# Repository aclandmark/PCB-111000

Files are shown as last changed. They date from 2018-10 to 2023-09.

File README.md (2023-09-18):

# PCB-111000

*/*/*/*/*/*/*/*/*/*/*/*/*/*/*/*/*/*/*/*/*/*/*/*/*/*/*/*/*/*/*/*/*/*/*/*/*/*/*/*/*/*/*/*/*/

This project is now obsolete.     The new version is PCB-111000_V2

The winAVR compiler has been replaced by Arduino and Studio 7

MOSFETS used to drive the display have been dispensed with

The pcb is set up usng a UNO and two sketches both of which are based on the sketch "UNO_as_an_AVR_programer"

Sample user programs have been updated in the light of the change from winAVR to Arduino.

The Nano_projects directory contains projects developed for PCB-111000_V2

*/*/*/*/*/*/*/*/*/*/*/*/*/*/*/*/*/*/*/*/*/*/*/*/*/*/*/*/*/*/*/*/*/*/*/*/*/*/*/*/*/*/*/*/*/*/*/*/

56 Projects for the novice C programmer -   Excludes programmer firm ware

Purpose: To introduce newcomers to C-programming for Atmega micro-controllers using the WinAVR compiler.  Programmers, target devices and a display are all provided on the pcb.  Sample user programs are provided to illustrate various applications such as transferring data to and from a PC, reading switches and driving a display.  Finished projects such as a stop watch, reaction time tester or calculator can be operated independently of a PC provided that a 5V USB supply is available.

PCB 111000 Hardware:

    1. An Atmega 328 that drives an 8 digit 7 segment display and downloads user code to an Atmega 168. 
    2. An Atmega 168 for which the user writes simple C-programs.  
    3. Three switches that can be used to provide inputs for the Atmega 168.
    4. An FTDI 230X USB to UART bridge that enables the PCB to be connected to a PC.
    5. A programming interface:  This is normally used to program the Atmega 168 but can also be used 
       to update the Atmega 328 code.
    6. An I2C interface via which user code controls the display.

PCB 111000 Software:

    1. A basic Atmega programmer that resides in the boot partition of the Atmega 328.
    2. An application that drives the display, hosts an I2C interface and includes other functions 
       including a clock/stop watch and arithmetic (known as the mini-OS).
    3. An Atmega 328 programmer that can be downloaded onto the Atmega 168.
    4. Subroutine library to support user code.

Test_file_change

Link to relevent AVRfreaks project

https://github.com/MicrochipTech/avrfreaks-projects/tree/main/projects/pcb-111000-winavr-taster-pcb

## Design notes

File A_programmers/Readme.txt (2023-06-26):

ATMEGA_project_work_BKP_30_Sept_2022\
I2C_apps_project_V10\
Programmers

For compatible programmers

Used in mini-OS_Version_20
2_pcb_Bootloader_V4_21_CA
3_pcb_Bootloader_V4_22_CC

Use  External programmer V2_30B	which ensures Auto cal runs on Atmega 328

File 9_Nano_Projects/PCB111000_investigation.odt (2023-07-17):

Development of Github_PCB-111000

Create new folders 9_Nano_Projects

and Resources_nano_projects

Go to ATMEGA_project_work_BKP_30_Sept_2022\I2C_apps_project_V10 and

Copy the files in 2_User_projects_V1_9\Resources_V12 to Resources_nano_projects

Create a new Arduino project 1_first_project

and save it under 9_Nano_Projects

Note that folder 1_first_project is created for the project

Open 2_User_projects_V1_9\….\….\Open Proj_1A1

Copy its contents into the Arduino project

Copy Proj_1A1 hex file and

Proj_1A1_header_file

into the 1_first_project folder along side the 1_first_project project

Rename the header file First_project_header

Initial tests

Upload the hex file to a PCB111000

Check it runs immediately following an -r- keypress

Gives Version data following an -x- keypress

Close and reopen the Arduino Project so that it includes the header file

Edit the #include statement to read #include "First_project_header.h"

Compile the project using Nano board Atmega 168 processor

Using setup_HW_basic;

and setup_HW

Check the following text is printed out OK

1 for OS version

2 for system data

3 Message from the OS (x to escape)

The Default project runs correctly

OS version

OS: I2C_V20_0_CA

System data:

SW information: Operating system I2C_V20_0_CA Projects V1_9 and Bootloader V4_21_CA. External programmer V2_30B

Actual operating system is Github_PCB-111000_V2\Mini-OS_V22

Update mini-OS

Github_PCB-111000 contains mini-OS version12 and 13.

Replace this OS with mini-OS_Version 20 copied from

ATMEGA_project_work_BKP_30_Sept_2022\I2C_apps_project_V10

Rebuilding mini-OS_V20 will require use of Atmel Studio 7.

Reprogramming the Atmega 328 with require the programs saved under

ATMEGA_project_work_BKP_30_Sept_2022\I2C_apps_project_V10

To update the mini-OS DO NOT EXPECT TO NEED TO DO THIS

At the p/r prompt put “4_Project_pcb_168_V2.30B” on the Atmega 168

At the ‘P’ prompt press

‘P’ to reprogram the mini-OS

‘E’ to update the “Hello world” file.

Note: Other programmers that should no longer be needed.

Version A: Same as Version B but B has one extra line to trigger auto cal of the 328.

4a_Project_pcb_328_V2.31A runs on an Atmega328

Programmer_pcb_328_V1.10 runs on a 328 and is used to put V2.30B on a 168 or replicate itself on another 328

6_BL_programmer_V1_5 was a development tool and is no longer required

If more boards are to be built a UNO will be used to put V2.30B onto an Atmega 168 and also calibrate it.

The Atmega 328 programmer applies the following config bytes to the 168

FF D5 C2 EB

V1.10 applies FF D7 E2 EB

Differences effect the brown out level and start up time.

New locations for user cal bytes Check carefully that these are always used

0x1FF User calibration byte

0x1FE User calibration byte

0x1FD Default calibration byte

0x1FC PRN generator random number HB

0x1FB PRN generator random number LB

Note: Only two locations are used here but write to EEPROM every 45 secs

2_User_projects_V1_9\Proj_9_System_projects\Proj_9A_168_manual_cal()

writes EEPROM location 0x1FA to zero.

No reason for this has been found and the line should be commented out

Problems

1 Note old problem with redefinition of

volatile char PCMSK0_mem, PCMSK2_mem;

in File I2C_subroutines_2

void I2C_Tx_float_display_control(void)

and #include "../Header_files/I_O_from switches.h"

Solution copied from PCB111000_UNO Compiles OK but not fully tested.

2 I2C_subroutines_2 line 121 SOLVED

Commented out for time being.

Calibration programs All OK

Copy the following two calibration routines to

9_Nano_Projects\System_programs

2_User_projects_V1_9\Proj_9A_168_manual_cal

and \Proj_9B_168_auto_cal

Compile with Arduino_nano_168 and calibrate two pcbs successfully.

Note Problem 2 above

Note: The Atmega 328 (mini-OS device calibrates itself automatically at every POR)

provided the DPDT is switched to the right.

1_first_project 12 examples

Example 1 Ramp with SW reset Tested OK

Example 1A Ramp with WDT generated reset Tested OK

Example 2 Back and forth with WDT Tested OK

Example 3 Chase (spurious wdr(); removed) Tested OK

Example 4 Single ellipse (spurious wdr(); removed) Tested OK

Example 5 Double ellipse (spurious wdr(); removed) Tested OK

Example 6 Upper/lower see saws Tested OK

Example 7 Moving top Tested OK

Example 7A Moving top (with reset on sw3) Tested OK

Example 8 Leds leapfrog WDT added Tested OK

Example 9 LEDS light up in random order (with reset) Tested OK

Example 10 Default program with WDT Tested OK

Tested with setup_HW_extra

Example_1 Modes 0 – 4 tested OK Saved as Example_1E

Example_4 Modes 0 – 4 tested OK Saved as Example_4E

Example_7 Modes 0 – 4 tested OK Saved as Example_7E

Example_9 Modes 0 – 4 tested OK Saved as Example_9E

2_Receiver_Transmitter_Basic

Example_1 Tested OK

Example_2 Tested OK

Example_3 Tested OK

Example_4 Reset implemented Tested OK

Example_5 Reset implemented Tested OK

Example_6 Reset implemented Tested OK

Example_7 Tested OK

Example_8 Tested OK

Example_9 Tested OK

Tested with setup_HW_extra

Example_1

Example_3

Example_5

Example_7

3_Interrupts_and_switches

Basic HW HW_Extra

3A_UART_timer_interrupts OK OK

3B_Pin_Change_Interrupt OK OK

3C_reaction_time_tester OK OK

3D_timer_PCI_interrupts OK OK

3E_Keypress_logger OK OK

3F_Prime_numbers OK OK

3G_Prime_numbers_plus OK OK

4_binary_and_bit_operations

1_Bit_ops_1 OK OK

2_Bit_ops_2 OK OK

3_Division_subroutine OK OK

4_Char_to_binary OK OK

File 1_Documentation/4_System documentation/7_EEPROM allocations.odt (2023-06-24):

Atmega 328: the first 0x200 bytes. These are reserved for user data

Bytes 0-1 First address available for numeric data

Byte 2 Number of bytes used for numeric data

Bytes 3-4 First address reserved for the application

Bytes 5-0x1FF Available for strings and numeric data

As supplied on the project pcb, bytes 5 to 0x1FB are occupied by strings.

No space is reserved for use by the mini-OS and no numeric data is stored.

Locations 0x01FC, D, E and F are unused.

Atmega 328: The second 200 bytes These are reserved for use by the mini-OS

Bytes 0x200 – 0x3F6 contain a copy of the strings required to use the Atmega 168 as a programmer.

0x3F7 to 0x3FA: These 4 bytes are not used.

0x3FB controls display intensity

0x3FC contains 1 for diagnostic mode (user pressed 'x' at the “p/r...” prompt) otherwise contains 0.

0x3FD contains the default value of OSCCAL (supplied by Atmel)

0x3FE and 0x3FF contain the user calibration values of OSCCAL.

Atmega 168 bytes 0-0x1FF

Bytes 0 – 0x1F6 : These contain strings used when the Atmega 168 is programmed with “1_ATMEGA_Programmer_V2.29A” for updating the mini-OS or programming the Atmega 328 EEPROM.

Note: this space can be overwritten by project SW and the strings restored when needed.

0x1F7 and 0x1F8 User cal byte

0x1F9 Default calibration byte

0x1FA – 0x1FD 4 unused bytes

0x1FE and 0x1FF Seed for 16 bit PRN generator

Modified as below

0x1FF PRN generator random number HB

0x1FE PRN generator random number LB

0x1FD PRN generator random number HB

0x1FC PRN generator random number LB

0x1FB PRN generator random number HB

0x1FA PRN generator random number LB

0x1F6 PRN EEPROM location offset 0, 1 or 2

Programming the Atmega 168 EEPROM

This is normally done on the programmer pcb using “1_ATMEGA_Programmer_V1.08” running on the Atmega 328.

Echo the “User Prompt” and then press 'P', 'E' and 'W'.

Note:

The Atmega 168 flash should also be programmed with 1_ATMEGA_Programmer_V2.29A.hex”

Programming the Atmega 328 EEPROM

This is normally done on the project PCB using “1_ATMEGA_Programmer_V2.29A.hex” running on the Atmega 168.

When programming the EEPROM press

"E" to program addresses 5 to 0x1FF or

"e" to program addresses 0x200 to 0x3FD or

"D" to delete the entire EEPROM up to 0x3FD (preserves cal bytes)

When verifying the target EEPROM press "r" or "R".

Note: An Atmega 328 programmed with “1_ATMEGA_Programmer_V1.08” can be soldered onto a project pcb if an unprogrammed Atmega 168 has already been soldered in.

C-programming for beginners: EEPROM allocations

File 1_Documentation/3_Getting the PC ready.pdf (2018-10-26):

PCB 111000: Getting the project PC ready

Disclaimers

PCB 111000 has been developed for educational purposes only. All associated software is supplied “as is” with no implied warranty or assumption of fitness for any purpose.

Instructions presented below involve making changes to a PC. They should only be carried out by a competent person who judges that to do so will in no way impair the computer performance or put at risk in any way the data already stored on it. Permission of the owner of the PC should also be sought.

Please also see disclaimers published with WinAVR.

Summary of the steps involved

Getting the PC ready involves carrying out the following steps.

Downloading and installing the WinAVR compiler and Programmers Notepad (pn) Fixing an error in the WinAVR installation
Doing a test compilation
Downloading drivers for the FX230 USB chip
Downloading a terminal program
Running the test project
Downloading a bit of help from the web
Accessing the WinAVR programs

Downloading WinAVR and programmers notepad (pn)
Go to
https://sourceforge.net/projects/winavr/files/WinAVR/20100110/
Download and run WinAVR-20100110-install.exe.
Select all the defaults i.e.
Install in the root directory, Install files, Add directories to path, Install programmers notepad. After completing the installation navigate to C:\WinAVR-20100110\pn.
Right click on the “pn” application and select “Create shortcut”.
Drag and drop the short cut onto the desktop.

Fixing the Installation error Before proceeding there may be an installation error to deal with. Check the reviews tab on the download page to determine whether or not it has been fixed. The problem may be because WinAVR is installed in the root directory rather than under “Program Files(x86)”. There are various ways of getting around it. The option selected here is to go to the following web page which discusses the problem in some detail http://www.avrfreaks.net/forum/windows-81-compilation-error

Then click on the link: http://www.madwizard.org/download/electronics/msys-1.0-vista64.zip This downloads the file “msys-1.0-vista64.zip”. Extract file “msys-1.0.dll”.
Use it to replace the file of the same name in the following directory: WinAVR-20100110\utils\bin.

Doing a test compilation (shows screen shot of programmers notepad (pn)

Open pn from the desktop.

The first time this is done the dialogue boxes “Text Clips”, “tags”, “projects” and “scripts” are all present. They are not used by the PCB 111000 projects can all be closed.

Open the first User project “Proj_1A.c”.
Then click on Tools:
[WinAVR]Make All.
An Output dialogue box tracks progress. The important thing apart from the absence of errors is the amount of program and data space used: 17.5% and 6.5% in this case.

Click on Tools:
[WinAVR]Make Clean
to delete files generated by the compiler that are not used by PCB 111000 projects. (Note the “makefile” has been changed slightly to ensure
that the .hex file is not also deleted.)

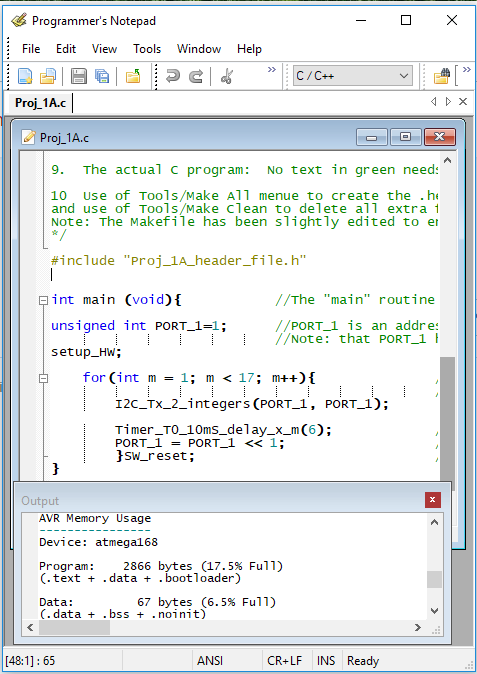
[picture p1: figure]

Downloading drivers for the FX230 USB chip
Having connected PCB 111000 to the PC for the first time this usually happens completely automatically in several minutes. Opening “device manager” enables this process to be tracked and also reveals the “comm port number” assigned to the pcb which should be remembered.

Downloading a terminal program
The terminal program enables PCB 111000 to communicate with a PC.

Two programs have been used during development of the PCB 111000 projects. The first is Br@y++ for which there are several versions. The simplest and most suitable can be obtained by going to
https://www.avrfreaks.net/forum/where-download-brays-terminal and then clicking on http://www.smileymicros.com/download/term20040714.zip?&MMN_position=42:42

Alternatively go to https://sites.google.com/site/terminalbpp/ Version Terminal20130116 is know to be suitable (but click the auto scroll box). This version must be used if the "comm port number exceeds 7.
Once the program has been downloaded it can be copied to the desktop or a short cut can be used if wished.

TeraTerm: This is a good alternative. A google search will quickly locate it.
(For example try https://tera-term.en.lo4d.com/). When installing Tera Term accept all the default settings.

Setting up the Br@y++ terminal program (includes a screen shot of Br@y++)

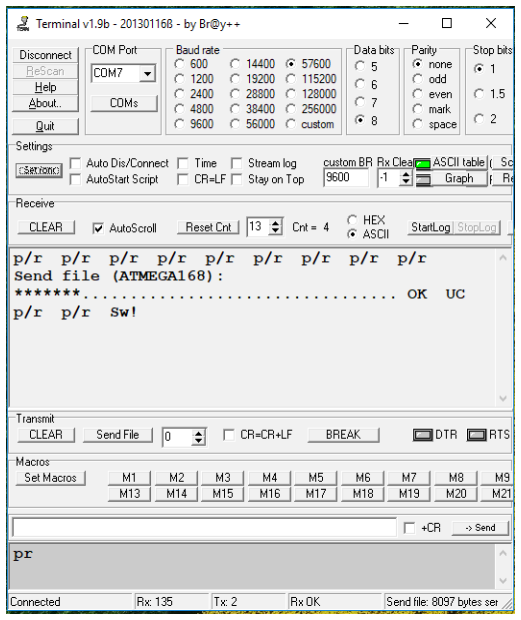
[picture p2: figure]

Connect PCB 111000 to the PC before
opening the terminal program.

The program automatically scans the USB ports and assuming that PCB 111000 is detected it is then necessary to select the correct “comm port number” and click on the “connect” button.

Then set the program as follows: Baud rate: 57600, 8 data bits, 1 stop bit, no parity and no flow control. Click the auto scroll box (if present) and adjust the font.

Note the two text boxes, one for receive and one for transmit. Ensure that the cursor has been placed in the lower box before typing the characters “p” and “r” which will then be transmitted.

Running a test program
Switch the DPDT switch to the RHS.
Press the vertical push button switch.
The Terminal program should display the user prompt p/r p/r …… Press -p- on the keyboard.
The message “Send file (ATMEGA168):” will be displayed
Send the file Proj_1A .hex.
At the p/r prompt press -r- and operate the DPDT switch when instructed. The PCB 111000 leds should now flash.
If they do so then setup and installation have been completed successfully

Setting up the Terra Term program (includes a screen shot of Tera Term)

Connect PCB 111000 to the PC before
opening the terminal program.

As soon as the dialogue box appears click on the serial button and then click on OK (assuming that the PCB 111000 has been detected).

Using the “setup menu” select serial port”, Set the baud rate to 57600 and operate the pcb switches so that the p/r.... prompt appears.
Then select a suitable font.
Finally use “Setup/Save setup” selecting the name “TERATERM”.

The next time Tera Term is used it will start up as wanted immediately.

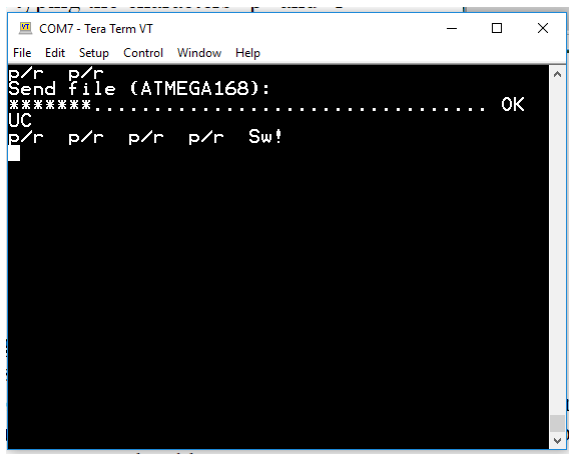
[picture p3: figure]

Note: There are no separate Receive and Transmit boxes and key presses are not echoed

Downloading a bit of help from the web
The following resource gives an excellent introduction to C and the Atmega devices and also gives help in driving the Br@y++ terminal and programmers notepad.
Do a google search on “C Programming for Microcontrollers”. This leads to the book by Joe Pardue of SmileyMicros.com
(Or try “https://epdf.tips/c-programming-for-microcontrollers.html”.)

Accessing the WinAVR programs

Left click in the “Windows” icon or press the “Windows” key.
Then scroll down the list of programs until the WinAVR-20100110 directory is reached.
Open it to reveal various applications and manuals any of which can be pinned to the start bar if required.

Mfile[WinAVR] is used to create “makefiles” which together with “pn” control the operation of the WinAVR compiler on behalf of the user.

Note: There is no need at this stage to access any of these programs. “Programmers notepads”(pn) acts as a development environment and automatically calls WinAVR when required. Additionally copies of “makefile” are already included with each project.

Operation (overview only)

1. Operation is controlled via two switches.
2. A double pole double throw (DPDT) which switches the USB bridge between the Atmega 328 and 168 and controls the external reset pin of the Atmega 168 (see photograph).
3. A push button (PB) which provides an external reset to the Atmega 328, which in turn initiates the bootloader causing it to generate the following user prompt “p/r p/r p/r.........”.

### 4. Operation of the pcb when power is applied:

5. The Atmega 328 automatically runs the mini-OS and provided that the Atmega 168 is connected to the USB bridge the user code will run (even from a 5V supply).

### 6. Programming the Atmega 168 and then allowing it to run:

7. Connect the pcb to a PC run the terminal program and select a Baud rate of 57600.
8. Use the DPDT to connect the Atmega 328 to the PC.
9. Operate the PB, press “p” at the user prompt and send the hex file when requested.
10. Press “r” when the user prompt is repeated, then operate the DPDT when requested.

Photographs of the PCB

View of the Atmega 168
Pin 1 closest to the DPDT

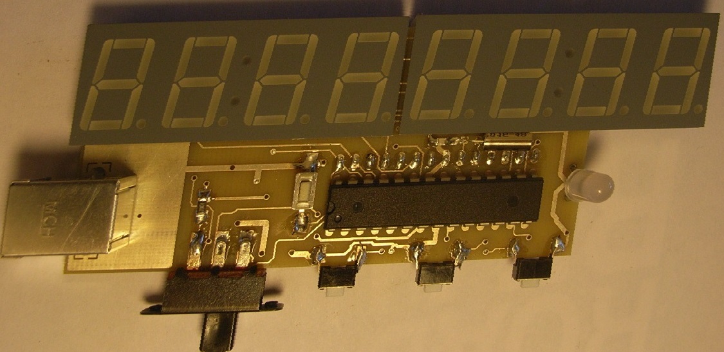
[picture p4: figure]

Note the DPDT switch

To connect the USB bridge to the Atmega 328 push the slider to the right.
To connect the Atmega 168 push it to the left.

Note the vertical push button switch.

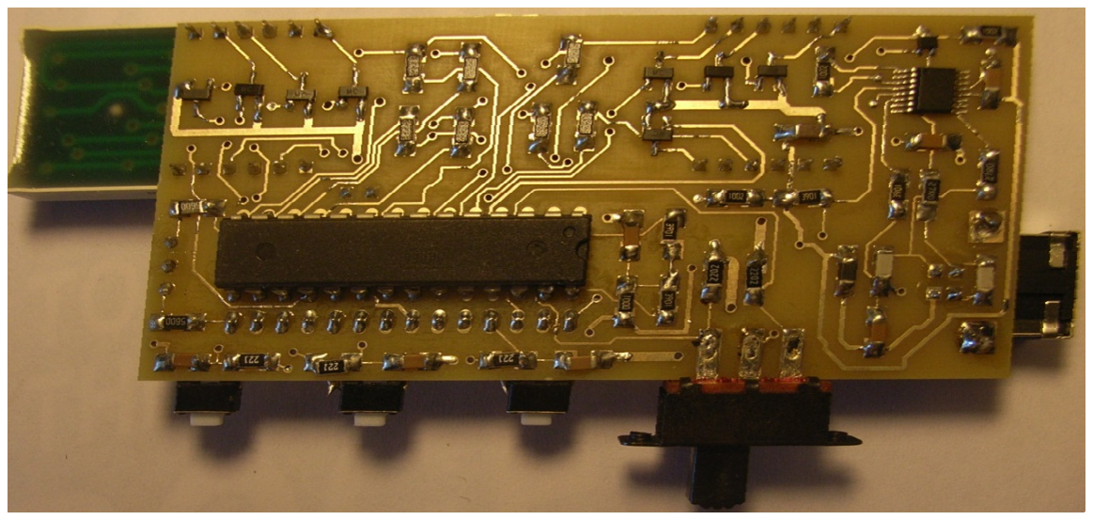
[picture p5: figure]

View of the Atmega 328
Pin 1 closest to the DPDT

Note the three horizontal switches that can be used to provide inputs for the Atmega

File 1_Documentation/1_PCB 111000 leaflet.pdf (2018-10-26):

Presenting PCB 111000: 56 Projects for the novice C-programmer

Features Atmega devices, programmer and mini-OS and Introduces the free WinAVR compiler

Target audience: Anyone wishing to try out WinAVR, who also wants a basic pcb to check that they have set up their WinAVR development environment correctly without having to worry about: hardware, programmers, configuration bytes, makefiles, projects, power supplies or any knowledge of electronics and

1. Who would like a brief introduction to writing C for the Atmega family of devices and using it to set up some of the on-chip peripherals.
2. Who would like sample projects, each of which comes with a commentary and provide an introduction to:
a. Basic C features including: loops, strings, variables, types, logic, binary, hex.
b. Basic hard ware features including: Timer/counters, the watchdog timer, the UART, interrupts, the EEPROM, Reset functions, displaying numbers, data input using the user switches, the I2C bus.
c. The WinAVR maths library functions and some of the I/O subroutines.
3. Who would like a platform on which to try out some on the numerous program segments available on internet forums.

System description

The pcb contains the following circuit blocks:

1. An Atmega 328 that drives an 8 digit 7 segment display and downloads user code to an Atmega 168. (See Figure overleaf.)
2. An ATMEGA 168 for which the user writes simple C-programs
3. Three switches that can be used to provide inputs for the ATMEGA 168
4. An FTDI 230X USB bridge that enables the module to be connected to a PC.
5. A programming interface: This is normally used to program the ATMEGA 168 but can also be used to update the ATMEGA 328 code.
6. An I2C interface via which user code controls the display.

System Diagram

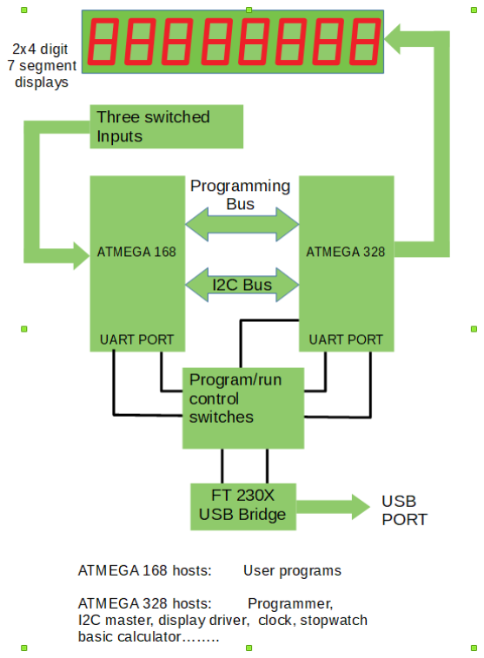
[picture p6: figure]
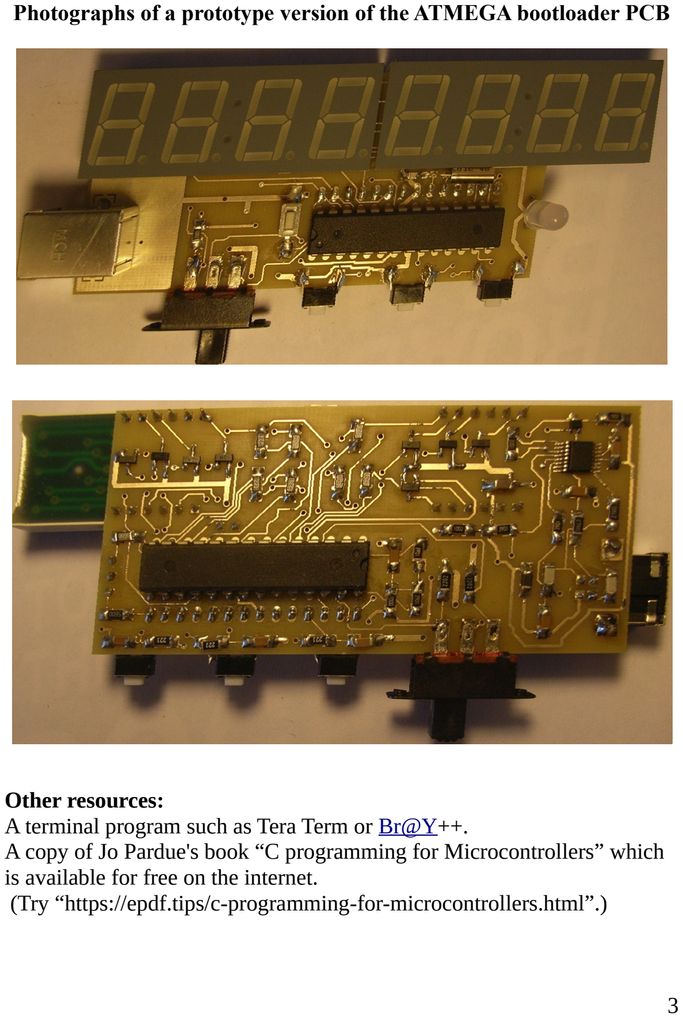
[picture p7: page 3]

Photographs of a prototype version of the ATMEGA bootloader PCB

Other resources:
A terminal program such as Tera Term or Br@Y++.
A copy of Jo Pardue's book “C programming for Microcontrollers” which is available for free on the internet.
(Try “https://epdf.tips/c-programming-for-microcontrollers.html”.)

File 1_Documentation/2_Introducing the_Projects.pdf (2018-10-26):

PCB 111000: Introducing the Projects

It is hoped that newcomers to the C programming language and microcontrollers will find that these projects offer them a basic introduction to:

the WinAVR development system, Programmers notepad and the makefile
the C-programming language and the ATMEGA hard ware (HW)
numbers in binary and visual form and logical and numeric operations

It is also hoped that the projects will offer
A bit of fun to share with friends
The odd useful application such as a clock/ stop watch or simple calculator Templates upon which newcomers can develop their own projects

Note: It is not intended that these projects be substituted for a C course or demonstrate the accepted or optimum way of doing things.

The Projects Projects are grouped into nine separate directories. Proj_1_Led_display_32_element
Proj_2_Led_display_56_element
Proj_3_numbers_and_strings
Proj_4_Data_entry_PCI
Proj_5_Clocks_and_stop_watches Proj_6_Logic_the_EEPROM_and_more Proj_7_Real_numbers
Proj_8_Using_the_C_maths_library
Proj_9_System_projects

The idea is that that each project should explore one new topic, however this was often found to be too restrictive. It is therefore suggested that some projects are worth revisiting later on rather than struggling with when when things are not immediately clear.

Proj_1 and 2

These cover most of the basic C and HW features to be introduced including: The main routine and subroutines
Program flow control and structures
Defining data items and data arrays
Communicating with a PC
Strings and pointers
Displaying numbers
Timers (T0 to T2) and the watchdog timer (WDT)
The EEPROM (memory that survives power disconnection)
UART (Receiver/transmitter) for communication with a PC
The input/output pins (I/O pins)
System Reset: | Power on reset (POR), WDT reset and External reset
Interrupts: | Timer, WDT, UART, PCI (pin change interrupt)
I2C bus: | Which is used to share data between the two devices

PCB 111000: Introducing the Projects

Proj_3_numbers_and_strings These cover the askii code and numbers in string and binary format including:
Sending symbols, text and numeric strings to the PC
Entering integers at the keyboard and converting them to binary numbers
Sending binary numbers to the eight digit display and the PC
Scientific notation
Hex numbers
Division with rounding
Trapping overflow in multiplication

Proj_4_Data_entry_PCI These cover the operation of “pin change interrupt” including Configuring the Atmega device for PCI
Reading the three project switches responsible for generating a PCI
Delaying and restoring PCI (putting it on hold and responding later on)
Disabling PCI, Clearing PCI and switch bounce
Entering numeric data using switch presses.

Proj_5 Clocks_and_stop_watches Mainly just for fun including:
An attempt to produce something useful
A combined clock stop watch that makes more ambitious use of the I2C bus and an excuse to study mini-OS (Operating System) code in some detail.

Proj_6_Logic_the_EEPROM_and_more Odds and ends including: Saving strings to the EEPROM for use by a client program.
Logical and bit operations
Prime number generation
Fruit machine simulation

Proj_7_Real_numbers Explores the acquisition and processing of real numbers: Conversion of decimals numbers between 0 and 1 to binary and back again
Converting a real number into a fixed point binary number
Using twos complement to obtain a negative number
Conversion of a real number to a floating point number with 32 bits for the decimal part and eight bits for the exponent
Basic arithmetic with fixed point and floating point numbers

Proj_8_Using_the_C_maths_library Explores the use of the C library functions to
Input strings and numbers from the keyboard and print results to the screen Input and process data from a .csv file
Use of “sprintf” to display results on the 8 digit display.
Acquire floating point numbers from the project switches
Proj_9_System_projects | These include:
Re-calibration of both devices
Re-initialising the Atmega 168 EEPROM following its use for project work Confirming correct operation of the display one digit at a time.

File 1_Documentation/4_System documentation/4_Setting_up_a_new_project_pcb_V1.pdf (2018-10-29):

PCB 111000: Setting up a new project pcb

Step 1 Initial assembly

Assemble the pcb with all surface mount components, starting with the mini-MOSFET and then the FT230X USB transceiver. Finally add the USB socket and connect the pcb to a PC. The FTDI device will request drivers (via the internet or a disc). The pcb will then be assigned a “com port” number (watch “device manager” window for details). When this is complete load the switches and LED.

Step 2 Adding the Atmega 168 and 328.

Use the programmer pcb to program:

the flash (program memory) of an Atmega 168 with “1_ATMEGA_Programmer_V2.29A.hex”
and its EEPROM with “ATmega programmer_EEPROM strings.txt”.

(see “Sys_documentation\5_The_programmer_PCB_V1” and also calibrate the device if necessary.)

Fit it to the upper side of the project pcb, closest to the pcb edge and with Pin 1 closest to the DPDT. Connect the pcb to a PC and run a terminal program.
Switch the DPDT left and the Atmega 168 should generate the “User prompt P P P | ”
Press 'X' and the pcb should respond with the following message “Target not detected”.
An unprogrammed Atmega 328 should now be fitted to the lower side of the pcb (Pin 1 closest to the DPDT) and the watch crystal should also be added.

Note: When using the Atmega 168 running “1_ATMEGA_Programmer_V2.29A” to program the Atmega 328 responding to the user prompt with:

‘X’ sets the reset vector to location 0x0000
‘P’ sets it to the start of the boot partition
‘P’ is only required when the mini-OS is being programmed
Step 3 Loading the Atmega 328 with the mini-OS

Switch the DTDP to the left.
At the “User Prompt” press 'P' three times.
When requested send file

“1_I2C_V12_0_CC_part_1.hex”, then when the download stops send “2_I2C_V12_0_CC_part_2.hex” and finally send “3_AT_bootloader_V4_22_CC.hex”

Press 0 at the “intger(0-FF)?” prompt.

The programmer responds by verifying the number of instructions that have been programmed. Additional data given includes:
The programmed configuration bytes of the Atmega 328 for which critical parameters are:

PCB 111000: Setting up a new project pcb

Reset vector: Start of the bootloader code.
External reset, serial programming, watchdog under program control EEPROM preserved through “chip erase”
Use of internal 8MHz clock.
3.9V brown-out

The calibration bytes refer to the Atmega 168 programmer. If it has been calibrated by project SW then the calibration data is duplicated.

Step 4 Program the Atmega 328 EEPROM

At the “User Prompt.” press 'P', 'P', 'e', 'W'
At the “intger(0-FF)?” prompt press '0'.
Send text file “ATmega programmer_EEPROM strings.txt”.
Notice that the strings are loaded into locations 0x200 to 0x3F6.
Note: This area of the EEPROM is used to back-up the programmer strings required if the Atmega 168 is to host “AT_Programmer_V2.29A”.

Repeat the process but press 'P', 'P', 'E', 'W'
Send file “Hello_world.txt”
Note that the strings are stored between location 0x5 and 0x1FC (503 characters)
This file can be replaced by any similar file of size 507 characters or less which can also contain numbers (additional characters will be ignored).
The contents of the EEPROM can be verified by pressing PPER or PPer at the user prompt.
Step 5 Calibrating the Atmega 328

The mini-OS includes an auto-cal routine that runs when power is applied. However users can also run “Proj_9C_ATMEGA328_manual_cal” if desired.
To do this:
Switch the DPDT to the right and press the vertical push button switch.
Note the “p/r p/r p/r ….” user prompt. Press 'p'
Send file “Proj_9C.hex” when requested
Press 'r' and operate the DPDT switch
The manual calibration routine will now run.
Step 6 Testing the project_pcb

At this stage the display modules can safely be fitted. It is often found that one or more of the display segments fails to work due to a dry joint or solder bridge. Fault finding is complicated because the display is driven by a multiplexer.

Project “Proj_9E_Test_PCB_Assembly” is therefore supplied to test the operation of the assembly. The multiplexer is disabled and digits and segments can be individually tested and faults located if any fail to work.

PCB 111000: Setting up a new project pcb

Driving the digits and segments

View of pcb from track side showing the pins of one of the four digit displays.

Letters refer to the individual segments.
Numbers refer to the individual digits.

Pin 3 is not used. It is provided to drive a decimal point or colon depending on which display module is used.
Pin-out of the display modules

Looking at the pcb from above the digits are numbered from left to right as follows:

Dig 7 Dig 6 Dig 5 Dig 4 Dig 3 Dig 2 Dig 1 Dig 0

Looking at the circuit diagram two displays are shown. Dig 4 to 7 are in the upper display and dig 0 to 3 in the lower display.

All digits are driven by the Atmega 328 which is on the lower surface of the pcb.

The Atmega 328 pins that drive the digits are as follows:

Pin 19 drives dig 7 | Upper display pin 12
Pin 23 drives dig 6 | Upper display pin 9
Pin 24 drives dig 5 | Upper display pin 8
Pin 25 drives dig 4 | Upper display pin 6
Pin 14 drives dig 3 | Lower display pin 12
Pin 16 drives dig 2 | Lower display pin 9
Pin 17 drives dig 1 | Lower display pin 8
Pin 18 drives dig 0 | Lower display pin 6

The segments are driven by the Atmega 328 as follows: a pin 15
b | 4
c | 5
d | 6
e | 11
f | 11
g | 13

pin 1

7 | 12

6

B 3 2 F A 1
4 G C D E

Edge of PCB

PCB 111000: Setting up a new project pcb

Alternative method of setting up the project PCB firm ware

If the Atmega 168 is soldered onto the project pcb before its flash has been programmed:

Plug an Atmega 328 into the programming PCB and program
its program memory with “1_ATMEGA_Programmer_V1.08_Q.hex”.

(see “Sys_documentation\5_The_programmer_PCB_V1”)

Then press 'P', 'P', 'E', 'W' to program its EEPROM with “ATmega programmer_EEPROM strings.txt”. Note: Text will be loaded into addresses 0x200 to 0x3F6.

Solder this IC onto the project PCB and use it to program the Atmega168 with “1_ATMEGA_Programmer_V2.29A.hex” and then continue as above.

Note: Programming can also continue correctly even if the EEPROM of both devices are unprogrammed. However there will be almost no device generated prompts.

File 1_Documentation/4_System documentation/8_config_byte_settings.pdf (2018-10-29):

PCB 111000: Fuse settings for the Atmega devices

Fuse settings enable users to configure certain elements of the Atmega hardware (HW) at programming time. Once these choices have been made they stand until the device is reprogrammed. The following configuration choices have been made for the project and programmer devices:

The System Clock:

The internal 8MHz RC oscillator is selected
No clock prescaling is implemented
No clock output is implemented.
The start up timer (SUT) is either set to 65mS or is disabled.

Note
The SUT holds the device in reset to give the dc supply and clock frequency time to stabilize.
The SUT can be disabled if the brown out detector (BOD) selected. The BOD holds the device in reset until the dc supply reaches a preset level.

BOD detector
This is implemented for the project pcb so that it can safely be used with batteries.
The brown out voltage level is set to 2.7V ± 0.2V.

Note:
The BOD uses an internal 1.1V reference which it shares with the Analogue to digital converter (ADC). The ADC which is disabled is set to use AVCC as its voltage reference.
The BOD protects memory that can become corrupted if the dc supply momentarily dips by putting the chip into reset.

The boot partition (implemented on the project pcb Atmega 328).
This is implemented by:
Setting the size of the boot partition to 2048 words (4096 (0x1000) bytes)
Setting the reset vector to location 0x7000 (the start of the boot partition).

Note: Where no bootloader code is required the reset vector is set to location 0x0.
In this case the size specified for the boot partition is not important and the application code can use the entire 0x8000 byte memory space.

Other settings
External reset | Enabled
Debug wire | Not used
Serial programming | Enabled
Watch dog timer (WDT) | Under programmer control
EEPROM memory | Survives chip erase
Memory lock bytes | No memory lock features are enabled.
| This byte is always set to 0xEB

Note: Users should never need to change the Configuration bytes

PCB 111000: Fuse settings for the Atmega devices

Project PCB fuse settings for the Atmega 328
Extended fuse byte 0xFD
bit 7-3 These bits are not used, and are each set to 1 (their default value) bit 2-0 These bits (101) set the brown out voltage to 2.7V.
Fuse byte high 0xD0
bit 7 1 | External reset enabled
bit 6 1 | Debug facility disabled
bit 5 0 | Serial programming enabled
bit 4 1 | Watch dog timer under programmer control
bit 3 0 | EEPROM memory preserved during chip erase.
Bit 2 0 | Bits 1 and 2 set the size of the boot partition
bit 1 0 | A setting of 00 gives 2048 words the maximum possible size
bit 0 0 | Sets the reset vector to location 0x7000 (the start of the boot partition)
Fuse byte | 0xC2
bit 7 1 | Divide clock by 8 disabled
bit 6 1 | No external clock output
bit 5 0 | Bits 5 & 4 define the Start up time (SUT)
bit 4,3 0 | SUT is disabled since brown-out detector is set
bit 2 0 | Bits 3-0 select clock
bit 1 1 | These settings select
bit 0 0 | the 8MHz internal oscillator
Note: When only running a single application or when loaded onto a programming pcb the following changes are made to the Atmega 328 fuse bytes:
The extended fuse byte becomes 0xFF | The DOB is disabled
The fuse byte high becomes 0xD7 | The reset vector is location 0x0. Bits 1&2 are non-critical
The fuse byte becomes 0xE2 | SUT is set to 65mS
Fuse settings for the Atmega 168 when running projects
Extended fuse byte 0xFF
bit 7-3 These bits are not used, and are each set to 1 (their default value)
bit 2-1 These bits are used to set the size of the boot partition. Here their settings are not critical. Bit 0 This bit sets the reset vector to location 0x0.
Fuse byte high 0xD5 | Use D7 when running Programmer V2.29A (no BOD)
bit 7 1 | External reset enabled
bit 6 1 | Debug facility disabled
bit 5 0 | Serial programming enabled
bit 4 1 | Watch dog timer under programmer control
bit 3 0 | EEPROM memory preserved during chip erase.
Bit 2 1
Bit 1 0 Bits 0 – 2 set the brown-out level to 2.7V.
Bit 0 1
Fuse byte C2 (The settings are identical to those of the Atmega 328) Use E2 when running Programmer V2.29A (65mS SUT)

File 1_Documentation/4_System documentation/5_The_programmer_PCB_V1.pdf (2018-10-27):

PCB 111000: The_programmer_PCB

The programmer_PCB is almost identical to the project_PCB however the Atmega 328 is loaded with “4_ATMEGA_Programmer_V1.08_T.hex”. The Atmega 168 is replaced with a dil socket (dual in line). Watch crystals are connected between pins 9 and 10 of both ICs rather than just the Atmega 328. The vertical push button switch is not loaded nor are the three switched used to provide user input.

This pcb can used to:
1 | Calibrate an Atmega 168 using:
| “11_Auto_cal_168_V1_5.hex” and
| “13_Manual_cal_168_V2_5.hex”.
2 | Prepare the Atmega 168 for use in a project pcb by:
| Programming its flash with “6_ATMEGA_Programmer_V2.29A.hex”
| and its EEPROM with “Atmega programmer EEPROM strings .txt”
3 | Calibrate an Atmega 328 using:
| “12_Auto_cal_328_V1.hex” and
| “14_Manual_cal_328_V2.hex”
4 | Prepare the Atmega 328 for use in a project pcb or another programmer pcb by:
| Programming its flash with “5_ATMEGA_Programmer_V1.08_Q.hex”
| and its EEPROM with “Atmega programmer EEPROM strings .txt”

Note:
1 | hex files are stored in folder “5_Hex_file_bkps” and txt files are stored in folder “6_Text_files”.
2 | Switch the DPDT to the LHS to run the calibration programs and to the RHS to run the programmer.
3 | Two versions of the programmer are available:
| 4_ATMEGA_Programmer_V1.08_T and 5_ATMEGA_Programmer_V1.08_Q.
| These generate user prompts “T T T | ” and “Q Q Q …..” .
| A programmer loaded with “4_ATMEGA_Programmer_V1.08_T” should replicate itself with one running “5_ATMEGA_Programmer_V1.08_Q” and visa-versa to avoid bus contention issues.
4 | It is recommended that the programmer pcb is only used to program the Atmega 168 before it is loaded into a project pcb however it can be use to program the Atmega 328 instead.

PCB 111000: The_programmer_PCB

Programmer_V1.08 used to program an Atmega 168 (DPDT switched to the RHS)

The user responds by echoing the user prompt.
The message “ATMEGA168 detected. Press P, R or H.” appears on the PC screen. The user presses P (responses R and H are discontinued) and receives the message “Press -P- to send a program file or -E- to send a text file.”
Flash is programmed by pressing P and sending the files when requested
At the prompt “Intger(0-FF)?” press 0.
The programmer then verifies that the size of the .hex file is the same as the size of the file residing in the flash memory.

The following diagnostic information is also printed.
The programmer version i.e. SW v1.08.
The configuration bytes applied to the target.
The programmer calibration factor. (if this is repeated the programmer has been calibrated otherwise the default cal value is used).
The hex files sizes all of which should be identical.

The user prompt now reappears. If the user presses E at the “Press -P- to send a program file or -E- to send a text file.” prompt the following message appears:
“Press -W- to write to the EEPROM, -R- to read from it”.
For a new target IC the users presses W and sends the text file. This will need sending twice after which the users makes a random key press (AK?). The text file is then echoed to the screen with strings occupying locations from 0 to 0x1F6. (Note: locations 0x1F7 to 0x1FF are reserved for system use).

V1.08 used to program an Atmega 328

Programming an Atmega 328 follows almost identical lines however the EEPROM is programmed at locations 0x200 and above.

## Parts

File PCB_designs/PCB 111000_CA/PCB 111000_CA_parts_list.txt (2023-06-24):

Partlist

Two versions of PCB 111000 are available
PCB 111000_CC uses Common Cathode displays 
PCB 111000_CA Common Anode displays

PCB 2 layer board 85mm by 40mm

7_SEG1&2  CA56-12SURKWA	RS872-1907 or RS146-1581  or 872_1907P	Common Anode Red display		

IC1      FT230XS   	RS 757-0010 
IC2      ATMEGA 168 	RE 73-4276                              
IC3      ATMEGA 328    	RE 73-4281   
L1       CHOKE		RS 724-1582                    

BSS84		RS 436-8091P		TR2-9			8 OFF
2SK3018		RS 694-2812		TR10     		1 OFF

27R 		RS 679-1979		R1, R4			2 OFF
100R 		RS 223-2120		R10			1 OFF
220R 		RS 153-987		R19, R27, R28		3 OFF	(switch decoupling)	
330R		RS 721-9784
220R		RS 123-4356		R20-26			7 OFF (Segment drivers) 
560R 		RS 679-2225		R15,16			2 OFF	(dual LED drivers)
3K9  		RS 223-2344		R5-6, R17-18		4 OFF	
10K  		RS 223-2394		R2-3, R8, R14		4 OFF
22K 		RS 679-1917		R7, R9			2 OFF

18pF		RS 648-0935					2 off for crystal
47p		RS 391-028		C2, C5			2 OFF
10n		RS 264-4141		C1, C9, C15-17		5 OFF
100n		RS 264-4179		C3, C6			2 OFF + Extra decoupling
4.7uF		RS 691-1224		C4			1 OFF
1uF		RS 648-0733		Additional decoupling to IC pins
Xtal		RS 547-6985 or 478-9268	

SW1		RE 76-0100	DPDT							
SW2		RE 51-0709	NO push button (SM)		
SW3-5		RE51-0711	NO push button (with pins)	 

SKT1		RS 515-1967	USB socket			

LED1		RS228-5764 	CC_DUAL_LED (There is an error in the library. No worry!!)

Note RS is Radio Spares and RE is Rapid Electronics

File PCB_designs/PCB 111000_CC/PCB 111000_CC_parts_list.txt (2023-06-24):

Partlist

Two versions of PCB 111000 are available
PCB 111000_CC uses Common Cathode displays 
PCB 111000_CA Common Anode displays

PCB 2 layer board 85mm by 40mm

7_SEG1&2  CC versions			ok		

IC1      FT230XS   	RS 757-0010	ok 
IC2      ATMEGA 168 	RE 73-4276   	ok                           
IC3      ATMEGA 328    	RE 73-4281   	ok
L1       CHOKE		RS 724-1582 	ok                   
Transistor		RS 275-945	ZVN3306FTA x 8		ok
Transistor		RS 694-2812	2SK3018T106 X 1		ok

27R 		RS 679-1979		R1, R4			2 OFF					
100R 		RS 223-2120		R10			1 OFF					
220R 		RS 153-987		R19, R27, R28		3 OFF	(switch decoupling)			
330R		RS 721-9784										
220R		RS 123-4356		R20-26			7 OFF (Segment drivers) 
560R 		RS 679-2225		R15,16			2 OFF	(dual LED drivers)		
3K9  		RS 223-2344		R5-6, R17-18		4 OFF						
10K  		RS 223-2394		R2-3, R8, R14		4 OFF					
22K 		RS 679-1917		R7, R9			2 OFF					

18pF		RS 648-0935					2 off for crystal			
47p		RS 391-028		C2, C5			2 OFF					
10n		RS 264-4141		C1, C9, C15-17		5 OFF					
100n		RS 264-4179		C3, C6			2 OFF + Extra decoupling		
4.7uF		RS 691-1224		C4			1 OFF					
1uF		RS 648-0733		Additional decoupling to IC pins				
Xtal		RS 547-6985 (Large) or 478-9268	(order these)								

SW1		RE 76-0100	DPDT											
SW2		RE 51-0709	NO push button (SM)				
SW3-5		RE51-0711	NO push button (with pins)			 

SKT1		RS 515-1967	USB socket						

LED1		RS228-5764  0r RS171-2136	CC_DUAL_LED (There is an error in the library No worry!!)   

Note RS is Radio Spares and RE is Rapid Electronics

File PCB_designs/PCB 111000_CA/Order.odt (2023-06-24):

PCB 111000_CC 8 Project pcbs and two 2 programmer pcbs

7_SEG1&2 CA56-12SURKWA Require 16 Have 2 Purchase 14

RS 146-1581 Pack of 10 £2:50 each

RS 872-1954 £2:74 each x 4 Yellow

IC1 FT230XS RS 757-0010 10 OFF Purchase 4

IC2 ATMEGA 168 RE 73-4276 10 OFF Purchase 6 From RS

IC3 ATMEGA 328 RE 73-4281 10 OFF Purchase 4

L1 CHOKE RS 724-1582 10 OFF Purchase 10

BSS84 RS 436-8091P 8 OFF Purchase 54

2SK3018 RS 694-2812 1 OFF OK

Xtal RS 547-6985 or 478-9268 1 OFF OK

SW1 RE 76-0100 DPDT Purchase 10

SW2 RE 51-0709 NO push button (SM) Purchase 4

SW3-5 RE 51-0711 NO push button (with pins) Purchase 3

SKT1 RS 515-1967 USB socket Purchase 5

LED1 RS228-5764 CC_DUAL_LED Purchase 1

27R RS 679-1979 2 OFF Order 15

100R RS 223-2120 1 OFF OK

220R RS 123-4356 10 OFF Order 50

560R RS 679-2225 2 OFF Order 1

3K9 RS 223-2344 4 OFF Order 25

10K RS 223-2394 4 OFF OK

22K RS 679-1917 2 OFF OK

18pF RS 648-0935 2 off OK

47p RS 391-028 2 OFF Order 25

10n RS 264-4141 5 OFF Order 50

100n RS 264-4179 2+ OFF OK

4.7uF RS 691-1224 1 OFF 3 OFF

1uF RS 648-0733 IC pins OK

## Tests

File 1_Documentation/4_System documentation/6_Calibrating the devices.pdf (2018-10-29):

PCB 111000: Calibrating the devices

Both devices can be calibrated in the programming jig or after assembly in the project pcb.
User calibration factors are saved in the EEPROM.

Both Atmega devices used by the project pcb run off their internal 8MHz RC oscillators. The precise frequency of an individual oscillator is controlled by the value saved in its OSCCAL register which can be anything between 0 and 255. Plots of frequency error against OSCCAL are shown in the figure below. It can be seen that:

the frequency can be increased to a maximum of about 16MHz
and reduced to a minimum of about 5.5MHz
There is at least one value of OSCCAL for which the error is very small and is often two

The devices are supplied with a preset value of OSCCAL. This often provides sufficient accuracy to enable the pcb to communicate with a PC at a baud rate of at least 57.6kB. This cannot be guaranteed however and it may be necessary to reduce the baud rate significantly. Devices can therefore be calibrated using the programming pcb or after they have been loaded onto a project pcb. User calibration factors are generated which are stored in EEPROM as follows:

For the Atmega 328: in locations 0x3FE and 0x3FF.
For the Atmega 168: in locations 0x1F7 and 0x1F8.

A HW_setup macro called by all the projects checks these locations. If they are equal and of any value between 0x0F and 0xF0 it assumes that they are user defined calibration factors and copies them to OSCCAL the resister that the HW uses to calibrate its oscillator.

0 | 50 | 100 | 150 | 200 | 250

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
Performance of the 8 MHz internal RC oscillator

Typical Frequency Error as a Function of OSCCAL

OSCCAL

%

E

R

R

O

R

PCB 111000: Calibrating the devices

Calibrating the devices in the programming jig

The following programs are provided to calibrate devices in the programming jig:

Auto_cal_168 (or 328): This identifies to first suitable OSCCAL value and saves it to EEPROM.

Manual_cal_168 (or 328): This prints out the calibration error for 40 sequential values of OSCCAL and enables to user to select a suitable user calibration value.

Plot_cal_168 (or 328): This is used to produce plots (as shown above).

Auto cal is necessary when the default value of OSCCAL is not sufficiently good to enable sensible communication with a PC.

Calibrating the devices in the project pcb

The following programs are provided to calibrate devices in the project pcb:

Proj_9B_168_auto_cal:
Proj_9A/D_168/328_manual_cal

The mini_OS checks the calibration of the Atmega 328 at every POR and does an auto cal if necessary.

Emergency restoration of calibration factors

Note: Calibration programs will not normally accept unsuitable values for OSCCAL. However if the 328 EEPROM gets corrupted the clock frequency may be changed so the p/r user prompt becomes “garbage” and communication with the PC is severed. If this happens select the LHS for the DPDT switch. Power cycle the pcb and reconnect to the terminal program. Pause a moment, then select the RHS for the DPDT switch and finally press the vertical push button switch. This should restore the p/r prompt.

If communication with the Atmega 168 gets severed run its auto cal routine

Note: If the project macro setup_HW; is replace by setup_HW_E; the Atmega 328 calibration can be checked by pressing x instead of r at the p/r prompt. The user will be presented with a menu offering Version data or the option to perform a quick cal on the Atmega 328.
Also note that additional files will have to be included using the project header file.

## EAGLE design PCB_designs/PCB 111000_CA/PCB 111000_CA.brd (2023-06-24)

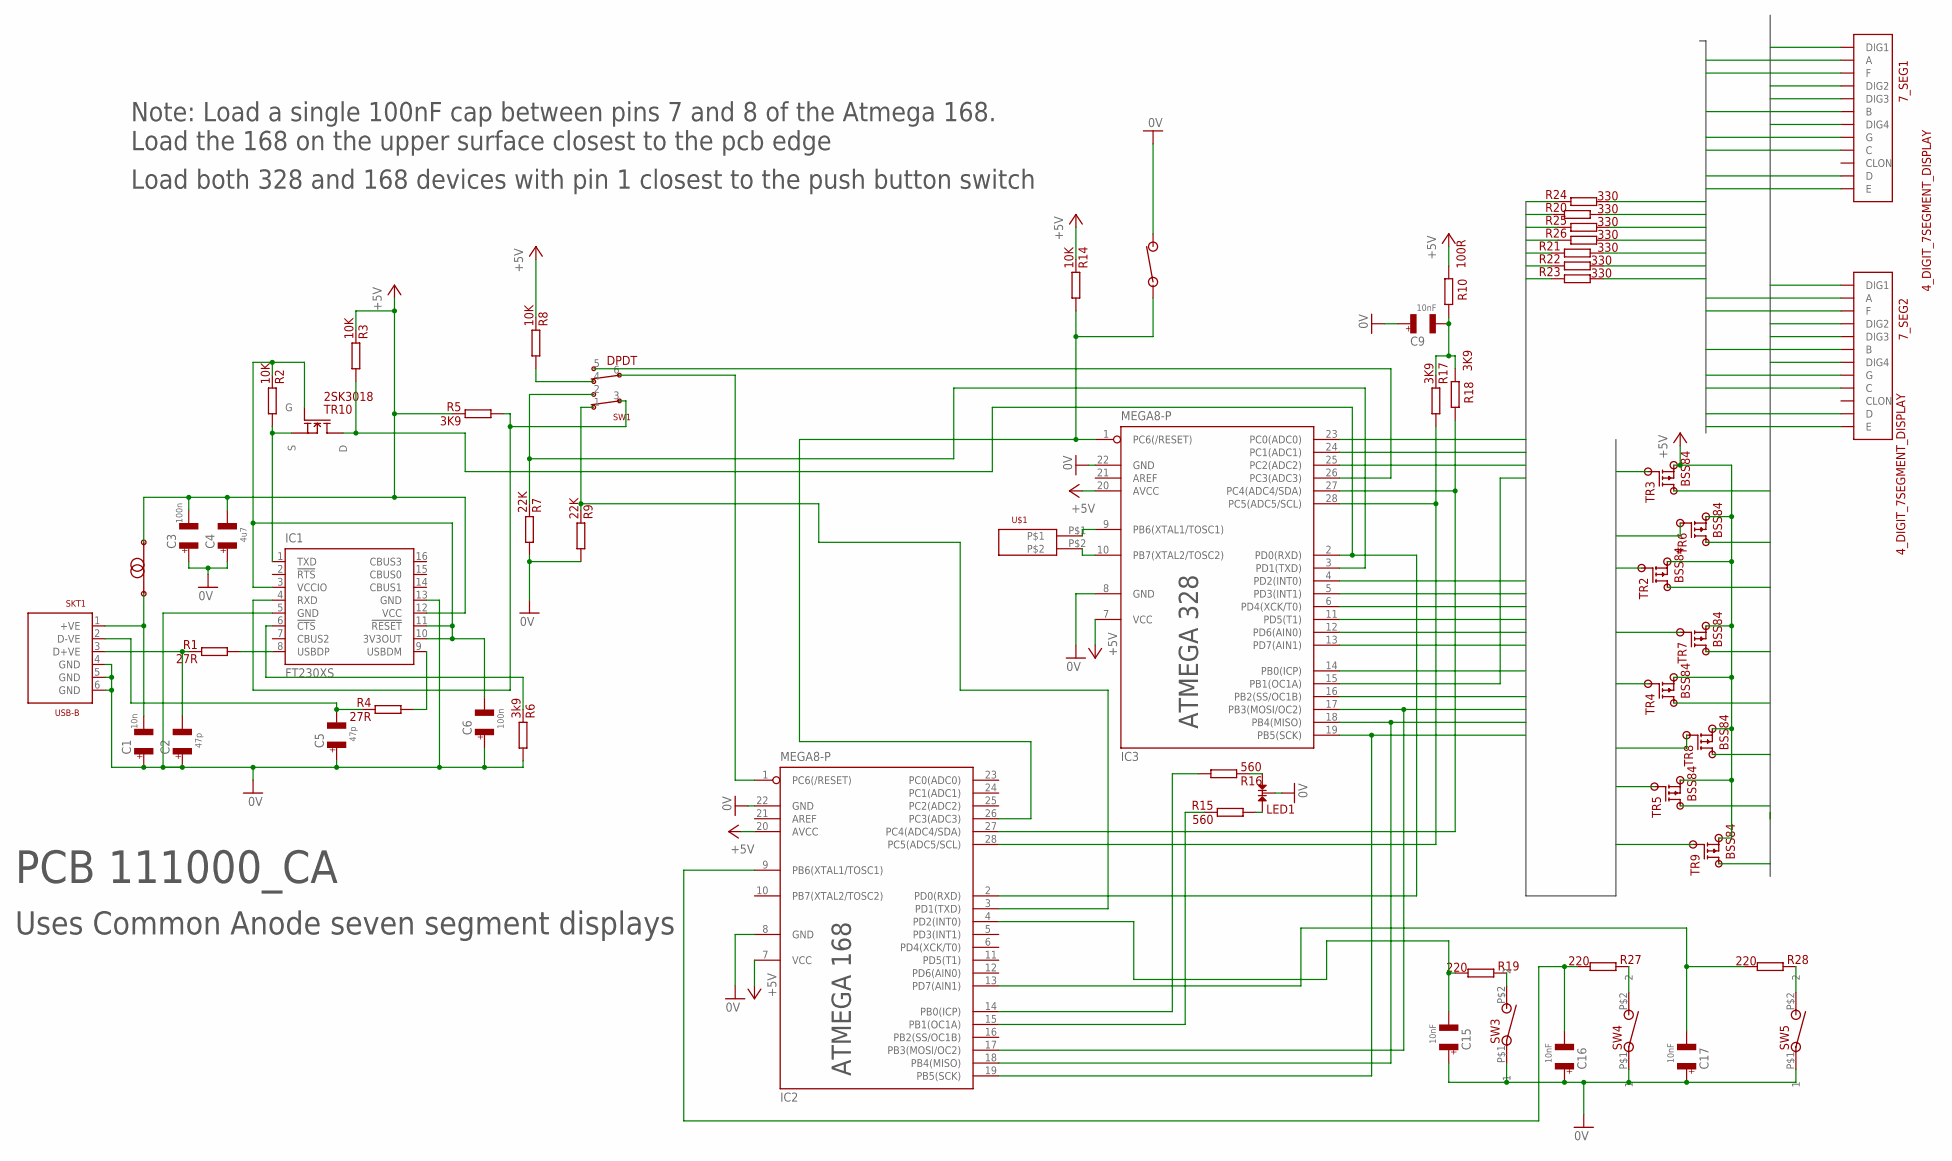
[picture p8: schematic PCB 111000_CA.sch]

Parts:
7_SEG1, 7_SEG2: 4_DIGIT_7SEGMENT_DISPLAY
C1: 10n; 1206
C2, C5: 47p; 1206
C3, C6: 100n; 1206
C4: 4u7; 1206
C9, C15, C16, C17: 10nF; 1206
IC1: FT230XS; SSOP16
IC2, IC3: MEGA8-P; DIL28-3
L1: CHOKE; 1206
LED1: LED; CA_DUAL_LED
R1, R4: 27R; 1206
R2, R3, R8, R14: 10K; 1206
R5, R17, R18: 3K9; 1206
R6: 3k9; 1206
R7, R9: 22K; 1206
R10: 100R; 1206
R15, R16: 560; 1206
R19, R27, R28: 220; 1206
R20, R21, R22, R23, R24, R25, R26: 330; 1206
SKT1: USB-B
SW1: DPDT; DPDT_SWITCH
SW2: NO_SW; SM_NO_PUSH_BUTTON
SW3, SW4, SW5: NO_PB_1; RE51-0711
TR2, TR3, TR4, TR5, TR6, TR7, TR8, TR9: BSS84; SOT23
TR10: 2SK3018
U$1: XTAL; XTAL_VIAS

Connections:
0V: C1.P$1 (1), C2.P$1 (1), C3.P$1 (1), C4.P$1 (1), C5.P$1 (1), C6.P$1 (1), C9.P$1 (1), C15.P$1 (1), C16.P$1 (1), C17.P$1 (1), IC1.5 (GND), IC1.13 (GND), IC2.8 (GND), IC2.22 (GND), IC3.8 (GND), IC3.22 (GND), LED1.2, R6.P$1, R7.P$1, R9.P$1, SKT1.4 (GND), SKT1.5 (GND), SKT1.6 (GND), SW2.P$2 (2), SW3.P$1 (1), SW4.P$1 (1), SW5.P$1 (1)
+5V: C3.P$2 (2), C4.P$2 (2), IC1.12 (VCC), IC2.7 (VCC), IC2.20 (AVCC), IC3.7 (VCC), IC3.20 (AVCC), L1.P$2 (2), R3.P$2, R5.P$2, R8.P$2, R10.P$2, R14.P$2, TR2.2 (S), TR3.2 (S), TR4.2 (S), TR5.2 (S), TR6.2 (S), TR7.2 (S), TR8.2 (S), TR9.2 (S)
DIGIT0: 7_SEG1.P$12 (DIG1), TR4.3 (D)
DIGIT1: 7_SEG1.P$9 (DIG2), TR8.3 (D)
DIGIT2: 7_SEG1.P$8 (DIG3), TR5.3 (D)
DIGIT3: 7_SEG1.P$6 (DIG4), TR9.3 (D)
DIGIT4: 7_SEG2.P$12 (DIG1), TR3.3 (D)
DIGIT5: 7_SEG2.P$9 (DIG2), TR6.3 (D)
DIGIT6: 7_SEG2.P$8 (DIG3), TR2.3 (D)
DIGIT7: 7_SEG2.P$6 (DIG4), TR7.3 (D)
DISPLAY_DRIVER0: IC3.15 (PB1(OC1A)), R24.P$2
DISPLAY_DRIVER1: IC3.4 (PD2(INT0)), R20.P$2
DISPLAY_DRIVER2: IC3.5 (PD3(INT1)), R25.P$2
DISPLAY_DRIVER3: IC3.6 (PD4(XCK/T0)), R26.P$2
DISPLAY_DRIVER4: IC3.11 (PD5(T1)), R21.P$2
DISPLAY_DRIVER5: IC3.12 (PD6(AIN0)), R22.P$2
DISPLAY_DRIVER6: IC3.13 (PD7(AIN1)), R23.P$2
DISPLAY_DRIVER8: IC3.14 (PB0(ICP)), TR3.1 (G)
DISPLAY_DRIVER9: IC3.16 (PB2(SS/OC1B)), TR6.1 (G)
DISPLAY_DRIVER10: IC2.17 (PB3(MOSI/OC2)), IC3.17 (PB3(MOSI/OC2)), TR2.1 (G)
DISPLAY_DRIVER11: IC2.18 (PB4(MISO)), IC3.18 (PB4(MISO)), TR7.1 (G)
DISPLAY_DRIVER12: IC2.19 (PB5(SCK)), IC3.19 (PB5(SCK)), TR4.1 (G)
DISPLAY_DRIVER13: IC3.23 (PC0(ADC0)), TR8.1 (G)
DISPLAY_DRIVER14: IC3.24 (PC1(ADC1)), TR5.1 (G)
DISPLAY_DRIVER15: IC3.25 (PC2(ADC2)), TR9.1 (G)
unnamed: IC2.14 (PB0(ICP)), R16.P$1
unnamed: IC2.15 (PB1(OC1A)), R15.P$2
unnamed: LED1.1, R15.P$1
unnamed: LED1.3, R16.P$2
unnamed: IC3.26 (PC3(ADC3)), SW1.5
unnamed: IC3.3 (PD1(TXD)), R7.P$2, SW1.2
unnamed: R27.P$2, SW4.P$2 (2)
unnamed: R19.P$2, SW3.P$2 (2)
unnamed: C6.P$2 (2), IC1.3 (VCCIO), IC1.10 (3V3OUT), IC1.11 (!RESET), R2.P$2, TR10.2 (G)
unnamed: IC3.9 (PB6(XTAL1/TOSC1)), U$1.P$1
unnamed: C17.P$2 (2), IC2.13 (PD7(AIN1)), R28.P$1
unnamed: IC3.10 (PB7(XTAL2/TOSC2)), U$1.P$2
unnamed: R8.P$1, SW1.4
unnamed: IC2.3 (PD1(TXD)), R9.P$2, SW1.1
unnamed: IC1.1 (TXD), R2.P$1, TR10.1 (S)
unnamed: R28.P$2, SW5.P$2 (2)
unnamed: C15.P$2 (2), IC2.4 (PD2(INT0)), R19.P$1
unnamed: IC1.9 (USBDM), R4.P$1
unnamed: C16.P$2 (2), IC2.9 (PB6(XTAL1/TOSC1)), R27.P$1
unnamed: C9.P$2 (2), R10.P$1, R17.P$2, R18.P$2
unnamed: IC1.8 (USBDP), R1.P$1
unnamed: IC2.1 (PC6(/RESET)), SW1.6
unnamed: C5.P$2 (2), R4.P$2, SKT1.2 (D-VE)
unnamed: C2.P$2 (2), R1.P$2, SKT1.3 (D+VE)
unnamed: C1.P$2 (2), L1.P$1 (1), SKT1.1 (+VE)
unnamed: IC2.26 (PC3(ADC3)), IC3.1 (PC6(/RESET)), R14.P$1, SW2.P$1 (1)
unnamed: IC1.6 (!CTS), R6.P$2
unnamed: IC1.4 (RXD), R5.P$1, SW1.3
unnamed: IC2.28 (PC5(ADC5/SCL)), IC3.28 (PC5(ADC5/SCL)), R17.P$1
unnamed: IC2.27 (PC4(ADC4/SDA)), IC3.27 (PC4(ADC4/SDA)), R18.P$1
unnamed: IC2.2 (PD0(RXD)), IC3.2 (PD0(RXD)), R3.P$1, TR10.3 (D)
SEVEN_SEG0: 7_SEG1.P$11 (A), 7_SEG2.P$11 (A), R24.P$1
SEVEN_SEG1: 7_SEG1.P$7 (B), 7_SEG2.P$7 (B), R20.P$1
SEVEN_SEG2: 7_SEG1.P$4 (C), 7_SEG2.P$4 (C), R25.P$1
SEVEN_SEG3: 7_SEG1.P$2 (D), 7_SEG2.P$2 (D), R26.P$1
SEVEN_SEG4: 7_SEG1.P$1 (E), 7_SEG2.P$1 (E), R21.P$1
SEVEN_SEG5: 7_SEG1.P$10 (F), 7_SEG2.P$10 (F), R22.P$1
SEVEN_SEG6: 7_SEG1.P$5 (G), 7_SEG2.P$5 (G), R23.P$1

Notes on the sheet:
Note: Load a single 100nF cap between pins 7 and 8 of the Atmega 168. Load the 168 on the upper surface closest to the pcb edge
Load both 328 and 168 devices with pin 1 closest to the push button switch
ATMEGA 168
ATMEGA 328
PCB 111000_CA
Uses Common Anode seven segment displays

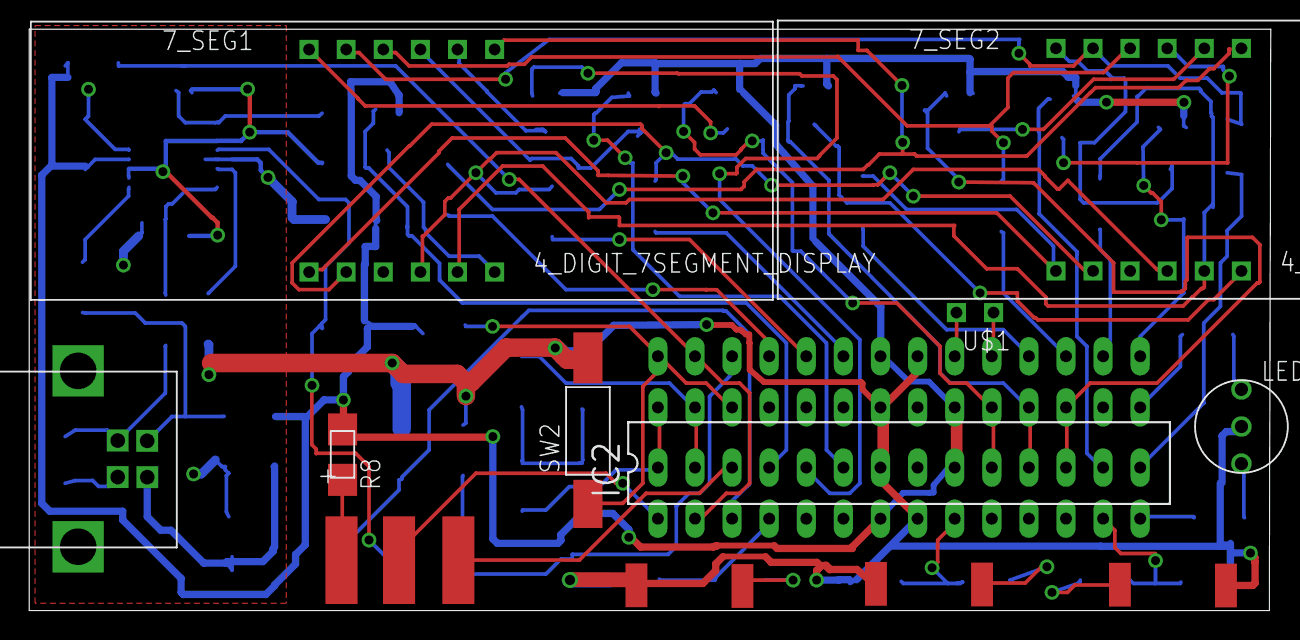
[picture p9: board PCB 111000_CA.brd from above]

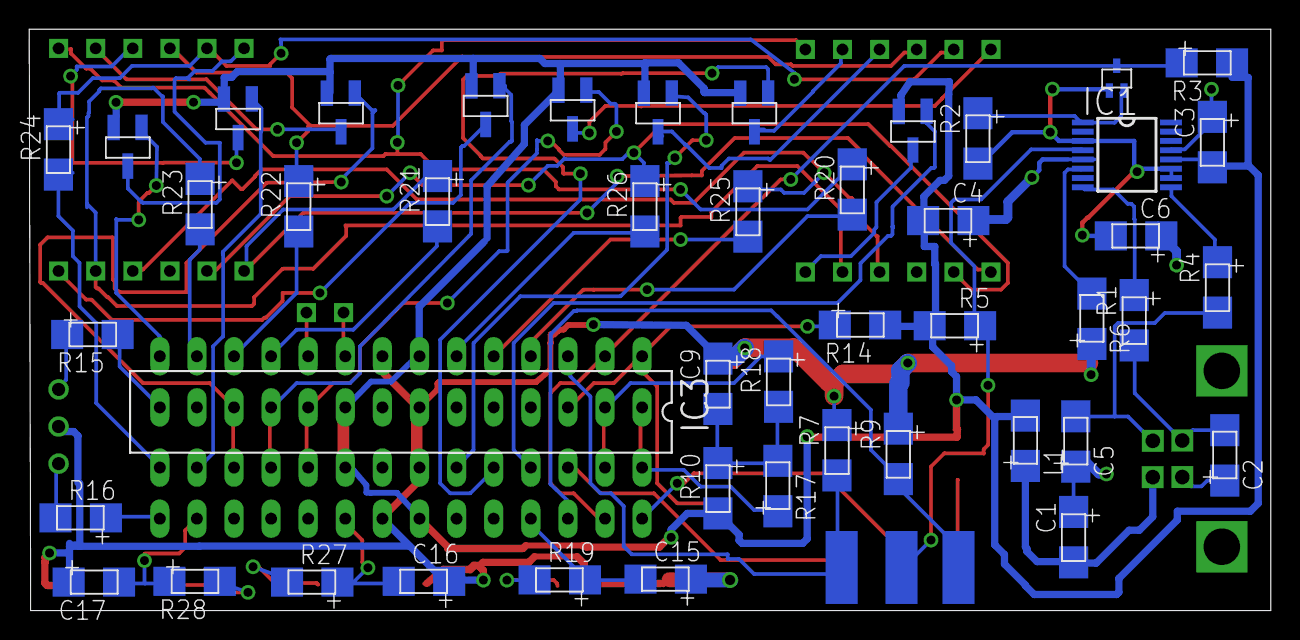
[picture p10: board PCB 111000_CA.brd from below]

Board: 2 copper layers, 85.0 x 39.8 mm, 58 parts (47 on the bottom side), 63 nets.

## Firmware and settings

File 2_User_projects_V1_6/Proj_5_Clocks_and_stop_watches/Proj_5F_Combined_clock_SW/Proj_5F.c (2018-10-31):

/*Proj_5F_Combined_clock_SW
*********************************************************/



/*IT INTRODUCES


1.	A crystal controlled clock/Stop Watch application.

Timing is provided using a 10mS I2C interrupt provided by the mini-OS that puts all clock/SW features under the 
control of the "Project_SW".


2.	Two wire serial interface TWI.
  
This is the term Atmel use for the Inter IC bus also known as the I-squared C or I2C bus.  Within the limits 
of these projects TWI and I2C hardware and protocols appear to be identical.


3.	An "atomic process".

Elapsed time is recorded in seconds in a variable known as "sec_counter".  It is updated by a TWI ISR and processed 
by "main" and other subroutines. If any of these processes were interrupted by the TWI ISR then "sec_counter" would 
get corrupted and the process would fail.
A different variable "sec_counter_V" is therefore defined.   This is the variable that the ISR updates directly.
Its value is copied to "sec_counter" at regular intervals. Global interrupts are disabled while this process is 
in progress, using the following code

	" cli(); sec_counter = sec_counter_V; sei();"

4.	Brown-out recovery.

BO is set to 2.7V to protect the device memories if the project_pcb is run from batteries which are subsequently allowed 
to become discharged. It is also used here to disable the display and reduce battery load.  
(Note: testing this facility has been rather limited).


5.	Project subroutine "I2C_initiate_10mS_ref();" 

This is used to initiate the 10mS TWI interrupt
Note:
The firmware can crash during a TWI data transfer and to guard against this happening the Watch dog timer has been 
implemented in Interrupt and System Reset Mode on both Atmega devices. The 7 digit clock can be changed to 8 digits 
(10ms tick) see optional line in subroutine “update_7_seg_display()”.



EEPROM USAGE

address 2	Initial mode: clock or SW
addresses 3-6	Time input by user
addresses 7-10 "sec_counter"
addresses 11-14 "clock time" in seconds: When a new SW is selected save the "sec_counter" in clock time and 
"reset sec_counter"
address 15 mode
address 16 The number of WD time outs.



USER INSTRUCTIONS

Connect to pc
press sw1 get message enter time (if not reset and repeat)
Enter time 24 hour clock
Power cycle to 5V supply if wanted 
press sw3 to start
press sw3 to toggle between clock and new SW
press sw2 to restore old SW
press sw1 to pause, blank and restore display
At initial POR press sw2 (rather that sw1) to get two SW's

To adjust time: Press SW3 to restore clock time
Then immediately press SW1
This will cause a WD time out
Release sw1 to increment time
sw3 to decrement time
Both switches to restore normal operation. 

Note: 
The number of WD time outs is given following a POR or programming.   
If a different project was run previously the EEPROM location may have 
been used for something else in which case the result will be erroneous.
A keypress interrupt has been implemented to test the operation of the WDT.


Switch location SW3(PD2) - SW2(PB6) - SW1(PD7)
PD2&7 call ISR(PCINT2_vect)
PB6 calls ISR(PCINT0_vect)
ISR on SW3 is never used.*/




#include "Proj_5F_header_file.h"



long clock_time_secs=0; 									//Value is seconds: Backed up in EEPROM when SW is selected


int main (void){

long SW_resume_time = 0;									//Value in seconds: Used when switching from clock to SW
long clock_resume_time=0;									//Value is seconds: Used when switching from SW to clock time


/*****************Normal program entry mode: Everything is OK********************************/

if((MCUSR & (1 << PORF)) || (MCUSR & (1 << EXTRF))){		//Detects POR or quit programming mode
MCUSR = 0;													//must reset status register
setup_HW;	
User_instructions;
String_to_PC("\r\n Number of WDTouts:  ");
Num_to_PC(10, eeprom_read_byte((uint8_t*)16));				//Sends number of WDTouts
newline();
for(int m = 0; m<=11; m++)
{eeprom_write_byte((uint8_t*)(m+7), 0);}					//clear BKP space

while(1){if(switch_2_down) {mode = 2;break;}				//Select timer or clock
		if(switch_1_down) {mode = 1;break;}}
while((switch_1_down) || (switch_2_down));

clock_time_secs=0;
old_mode = 0;
payload=2;}

/**********************************Brown out recovery mode************************************/

if(MCUSR & (1 << BORF)){
MCUSR &= (~(1 << BORF));									//Detect presence of brownout flag and reset it
setup_HW;

mode = 'G';													//Set new mode to 'G'
old_mode = eeprom_read_byte((uint8_t*)15);					//Obtain "old_mode" from EEPROM
sec_counter=eeprom_read_byte((uint8_t*)(10));				//Obtain "sec_counter" from EEPROM		
for(int m = 0; m<3; m++){
sec_counter = (sec_counter<< 8) + eeprom_read_byte((uint8_t*)(9-m));}

clock_time_secs=eeprom_read_byte((uint8_t*)(14)); 			//Obtain "clock_time_secs" from EEPROM
for(int m = 0; m<3; m++){
clock_time_secs = (clock_time_secs<< 8) + eeprom_read_byte((uint8_t*)(13-m));}
		
		sec_counter +=1;									//Fudge factor??
		clock_resume_time = sec_counter;
		sec_counter_V = sec_counter;						//Volatile version of "sec_counter"
		ms_counter=0;										//mSecs are not restored
		clock_time_long = clock_time_secs * 100;
		setup_64ms_WDT_with_interrupt;						//Re-establish WDT
		I2C_initiate_10mS_ref(); sei();}					//Reinitialise 10mS tick
		
		

/*****************WDT revovery mode (usually caused by failure of the I2C)**********************/

if(MCUSR & (1 << WDRF)){									//Detect watchdog timeout					
setup_HW													//This macro clears the WD flag
if((switch_1_up) && (switch_3_up))							//Normal WDTout (i.e. not user induced)
{eeprom_write_byte((uint8_t*)(16),(eeprom_read_byte((uint8_t*)(16)) + 1));}//Increment contents of EEPROM address 16

sec_counter=eeprom_read_byte((uint8_t*)(10));				//Read saved value of sec_counter from EEPROM		
for(int m = 0; m<3; m++){
sec_counter = (sec_counter<< 8)
+ eeprom_read_byte((uint8_t*)(9-m));}				

if((switch_1_down) && (switch_3_down)){					//User induced watch dog timeout:
while((switch_1_down) || (switch_3_down)){					//Use sw_1 and sw_3 to adjust time
if((switch_1_up) && (switch_3_down)){sec_counter += 1;}
if((switch_3_up) && (switch_1_down)){sec_counter -= 1;}
Timer_T0_10mS_delay_x_m(10);
Calculate_time();
digits[0]='0'; digits[1] = '0';							//Sets mS*10 to zero	masks mS*10			
I2C_Tx_8_byte_array(digits);}}								//Displays time as adjusted by user

mode = eeprom_read_byte((uint8_t*)15);						//Obtain "mode" and "clock_time_secs" from EEPROM
clock_time_secs=eeprom_read_byte((uint8_t*)(14)); 	
for(int m = 0; m<3; m++){
clock_time_secs = (clock_time_secs<< 8) + eeprom_read_byte((uint8_t*)(13-m));}
		
		sec_counter +=1;									//Fudge factor??
		clock_resume_time = sec_counter;
		sec_counter_V = sec_counter;						//Volatile version of "sec_counter"
		ms_counter=0;										//mSecs are not restored
		clock_time_long = clock_time_secs * 100;
		Calculate_time();
		payload=8;											//After WDT out update display
		setup_64ms_WDT_with_interrupt;						//Re-establish WDT
		I2C_initiate_10mS_ref();sei();}					//Reinitialise 10mS tick


/**************************Normal program continues********************************/

setup_and_enable_PCI;
disable_pci_on_sw3;	
disable_pci_on_sw2;
display_clear = 0;
	
UCSR0B |= (1 << RXCIE0); 									//Used to test operation of WDT only

 
while(1){													//Main loop: Continuously cycles through this loop (every 188uS??).  

switch(mode){
case 0: break;
case 1: set_time();											//Clock mode: "set_time()" requests start time  & saves it in "sec_counter"
mode = 'A';break;		
case 2: sec_counter = 0;									//SW mode: start at time zero															
		mode = 'A'; 
		break;
case 'A':	
	ms_counter = 0;
	sec_counter_V = sec_counter;							//Initialise sec_counter_V
	Calculate_time();Time_on_screen; 						//Converts time in seconds to string (Hr,Min and Sec)
	digits[0]='0'; digits[1] = '0';						//Sets mS*10 to zero	masks mS*10			
	I2C_Tx_8_byte_array(digits);							//Displays time 
	clock_resume_time = sec_counter;
	mode = 'E'; 
	break;
	
case 'E':													//Clock ready to start: Awaiting sw3 press
	if(switch_3_up); else{
	I2C_initiate_10mS_ref();								//Initiate TWI interrupt (every 10mS)
	sei();
	mode = 'B';
	setup_64ms_WDT_with_interrupt;}							//User input finished: Start WDT
	break;											

case 'B': if(!(TWI_flag)); 
else {TWI_flag = 0; Update_sec_counter;						//Clock running mode
old_mode = 'B'; 
if(((86400 + sec_counter - clock_resume_time)%86400>1) && ((switch_2_down) || (switch_3_down)))
{if(switch_3_down){clock_time_secs = clockTOstop_watch();mode = 'F';}
if(switch_2_down){SW_resume_time = restore_stop_watch(); mode = 'H';}}
else Timer();} 
break;														//Convert clock to stop watch

case 'F': if(!(TWI_flag)); 
else {TWI_flag = 0; Update_sec_counter;						//Stop watch mode			
old_mode = 'F';	
if(((sec_counter)>1) && ((switch_3_down)))
{clock_resume_time = restore_Clock();mode = 'B'; }
else Timer();}
break;														//Restore clock

case 'H': if(!(TWI_flag)); 
else {TWI_flag = 0; 	Update_sec_counter;					//Stop watch restored mode			
old_mode = 'H';	
if(((86400 + sec_counter-SW_resume_time)%86400 > 1) &&  (switch_3_down))
{clock_resume_time = restore_Clock();mode = 'B'; }
else Timer();}
break;	

case 'C':  
payload = 0; TWI_flag = 0; 
Update_sec_counter;	break;									//Stop watch/clock display paused: Tick continues

case 'G': payload = 0; TWI_flag = 0; Update_sec_counter; 
if (!(display_clear)) clear_display();break;				//blank display

case 'D': TWI_flag = 0;
restore_display();  mode = old_mode;						//Stop watch/clock display re-activated
break;}
Timer_T2_sub(T2_delay_2ms);
wdr();}}													//reset the watchdog



/*****************************************************************************************************************/

void Timer(){												//Calls "update_7_seg_display", to close one I2C transaction and sets "payload" to initiate the next one		
	digits[1] = ms_counter/10 + '0';						//Calculate mS display MSB
	digits[0] = ms_counter%10 + '0';						//Calculate mS display LSB
	if (!((digits[0] == '0')&&(digits[1] == '0')))		//For mS tick 0 to 99 only update mS display		                                                                                                                                                                                                                                                                                                                                                                                                                                                                                                            			
	{ms_on_screen_update; update_7_seg_display();}			//Update mS display
	if(!(ms_counter%100)){									//When 1 second tick occurs
	Calculate_time();										//Calculate time: Hr:Min:Sec
	Update_time_on_screen;									//Update screen
	update_7_seg_display();}								//Update display and complete the current I2C transaction
	if(ms_counter == 99)payload=8; else payload=2;}		//Set payload for next TWI_interrupt 8 for 1sec tick, 2 for 10mS tick



/*****************************************************************************************************************/

ISR(TWI_vect){												//Detects 10mS interrupt. Initiates I2C_transaction and responds by sending payload size
char Null_byte;
TWI_flag=1;													//Informs main loop that a 10mS tick has occurred
ms_counter = (ms_counter+1)%100; 							//mS counter continuously cycles through 0 to 100
if(!(ms_counter)) {sec_counter_V++;						//Volatile version of "sec_counter" increments every second
if(sec_counter_V == 86400)sec_counter_V = 0; 				//Roll-over for 24 hour clock
sec_counter_save=1;}										//Enables "sec_counter" to be updated from "sec_counter_V"
Null_byte =  TWDR;											//Detect slave address + slave transmit data command
TWDR = payload;												//Transmit payload value
TWCR = (1 << TWEN) | (1 << TWINT);							//clear interrupt but no ack required Next byte will be the last
while (!(TWCR & (1 << TWINT)));							//Wait for TWINT flag 
if (!(payload))
TWCR = (1 << TWINT) | (1 << TWEA) | (1 << TWEN) | (1 << TWIE);}	//No payload? Prepare for next 10ms interrupt



/*****************************************************************************************************************/

void update_7_seg_display(void){
char Null_byte;
cli();														//Pause twi interrupt
hold_PCI_on_sw1_and_sw3;
{digits[0] = digits[1]; digits[1] = 0;}					//Optional: masks 10mS digit
TWCR = (1 << TWINT) | (1 << TWEA) | (1 << TWEN);			//Enable slave mode and set Enable Acknowledge
while (!(TWCR & (1 << TWINT)));							//No interrupt: wait for comms from master
Null_byte =  TWDR;											//Read slave adress
for (int m = 0;  m < payload; m++){
TWDR = digits[m];											//Transmit data for display
if (m==(payload-1))TWCR = (1 << TWINT) | (1 << TWEN);		//last byte being transmitted now expect NACK in response
else{TWCR = (1 << TWINT) | (1 << TWEA) | (1 << TWEN);}	 //ACK pulse normally required
while (!(TWCR & (1 << TWINT)));}							//Clear interrupt
TWCR = (1 << TWINT) | (1 << TWEA) | (1 << TWEN) | (1 << TWIE);	//Prepare for next 10ms interrupt
restore_PCI_on_sw1_and_sw3;
sei();}														//re-enable twi interrupt
		


/*****************************************************************************************************************/

void Calculate_time(void){
Hours = sec_counter/3600;									//Obtain hours 0 to 23
Minutes = (sec_counter%3600)/60;							//Obtain minutes
Seconds = (sec_counter%3600)%60;							//Obtain seconds			
timer_utoa(Hours); HoursH = charH; HoursL = charL;			//Convert hours to string 
timer_utoa(Minutes); MinsH = charH; MinsL = charL; 		//Convert minutes to string
timer_utoa(Seconds); SecsH = charH; SecsL = charL; }		//Convert seconds to string										


/*****************************************************************************************************************/

void set_time(void){
unsigned int Two_sec_counter;								//Required because of difficulties combining long and char variables						

char clock_mode;
clock_mode = eeprom_read_byte((uint8_t*)0x02);				//Read mode. Default value is 255
switch(clock_mode){

case 255:													//Default mode: User enters time
String_to_PC("\r\nEnter start time Hours, Minutes and Seconds (24 hour clock, no spaces)\r\n");
while(isCharavailable(50) == 0){String_to_PC("T?  ");}		
		HoursH = receiveChar();			
		while(isCharavailable(5) == 0); HoursL = receiveChar();
		while(isCharavailable(5) == 0); MinsH = receiveChar();
		while(isCharavailable(5) == 0); MinsL = receiveChar();
		while(isCharavailable(5) == 0); SecsH = receiveChar();
		while(isCharavailable(5) == 0); SecsL= receiveChar();
		msecsH = 0; msecsL = 0;	
		Two_sec_counter = ((((HoursH-'0') * 10) + HoursL-'0') * 1800)\
		+ ((((MinsH-'0') * 10) + MinsL-'0') * 30) + ((SecsH-'0') * 10 + SecsL-'0')/2; 
		sec_counter = Two_sec_counter;
		sec_counter *= 2;							
		if (((SecsH-'0') * 10 + SecsL-'0')%2)sec_counter++;
		
		
		for(int m = 0; m<=3; m++){eeprom_write_byte((uint8_t*)(m+3),sec_counter >> (m*8));
		Timer_T0_sub(T0_delay_5ms);}						
		eeprom_write_byte((uint8_t*)(0x02),0);Timer_T0_sub(T0_delay_5ms);		
		break;
case 0: 
		sec_counter=eeprom_read_byte((uint8_t*)(6)); 		//Read start time and place in sec_counter
		for(int m = 0; m<3; m++){
		sec_counter = (sec_counter<< 8) + eeprom_read_byte((uint8_t*)(5-m));}
		eeprom_write_byte((uint8_t*)(0x02),255);break;		
default: eeprom_write_byte((uint8_t*)(0x02),255);
wdt_enable(WDTO_30MS); 
while(1);break;	}}											//Corrupt clock_mode variable: set to default value and restart



/*****************************************************************************************************************/

void timer_utoa(char n){									//converts an unsigned number to a string of digits
if (n>=10)
{charL = n%10;
charH = (n-charL)/10;
charL = charL + '0';
charH = charH + '0';}
else
{charH = '0'; charL = n + '0';}}



/*****************************************************************************************************************/

ISR(PCINT2_vect) {											//PORTB switch_1 interrupts
if(switch_1_up)return;										//Ignore interrupt on switch release
if(!(sw_de_bounce ())) return;								//Close ISR down if backup is in progress
if(switch_1_down) {											//Switch 1 used when user defined start time is required

if(switch_3_down){											//switch_3 does not generate an interrupt
if(mode != 'B')return;
else { 
payload = 8;sei(); while(1);}}								//User initiated WDTout used to adjust time 

switch(mode){
case 0: mode = 1; break;									//Enter the start timer
case 'H':
case 'F':
case 'B':  mode = 'C'; break;								//Mode B clock is running Mode C Display paused
case 'C':  mode = 'G'; break;								//Mode G clear display
case 'G':  mode = 'D';break;}}}							//Restore display



/*****************************************************************************************************************/

long clockTOstop_watch(void){								//Saves time before selecting stop watch display (i.e. resetting time to zero)
long clock_time_secs_L;
clock_time_long = (sec_counter * 100) + ms_counter; 		//Current time "secs*10 + ms" saved in global variable clock_time.
ms_counter = 0;												//Reset msecs
sec_counter = 0;											//Reset secs
clock_time_secs_L = clock_time_long/100;					//Ignore ms when saving clock time
update_7_seg_display();										//Runs "update_7_seg_display()" to complete the current I2C transaction
payload = 8;												//Set payload to 8 for full display update during next I2C transaction
while(!(ms_counter));										//Wait for next interrupt ms_counter increments from 0 to 1
TWI_flag = 0;												//Clear TWI_flag
for(int m = 0; m<=7; m++)digits[m] = '0';					//Clears all digits
Update_time_on_screen; ms_on_screen_update;					//Update screen
update_7_seg_display();										//Runs "update_7_seg_display()" to complete I2C transaction
payload=2;													//Payload of 2 required for next update
cli();sec_counter_V = 0;sei();								//Update volatile version of the sec_counter and return to "main loop"
return clock_time_secs_L;}



/*****************************************************************************************************************/

long restore_Clock(void){									//Restores time by adding "clock_time" to the current SW time
long time, clock_restore_time;
char x;
time = (sec_counter * 100) + ms_counter + clock_time_long;	//Add saved "clock_time" to SW time	to get current value of time			
sec_counter = time/100;										//Calculate new value of "sec_counter" and "ms_counter"
ms_counter = time%100 - 2;									//2mS fudge factor required for mseconds
if(sec_counter >=86400)sec_counter -=86400;				//compensates for 24Hr roll-over
update_7_seg_display();										//Run "update_7_seg_display()" to complete the current I2C transaction
x=ms_counter;												//Record "ms_counter"
clock_restore_time = sec_counter;							//saves "sec_counter" in "clock_restore_time"
Calculate_time();											//Calculate time Hr:Min:sec
digits[1] = ms_counter/10 + '0';							//Calculate mS display MSB
digits[0] = ms_counter%10 + '0';							//Calculate mS display LSB
Update_time_on_screen; ms_on_screen_update;					//Update stop watch screen display
payload = 8;												//Sets the payload to 8 ahead of next I2C transaction (update full disdplay)
while(ms_counter==x);										//Wait for next interrupt (ms_counter increments from x to x+1)
TWI_flag = 0;												//Set TWI_flag to zero
Update_time_on_screen; ms_on_screen_update;					//Full screen update
update_7_seg_display();										//Full display update (completes the current I2C transaction)
if(ms_counter == 99)payload=8; else payload=2;				//Enables contiguous 8 digit updates when necessary
cli();sec_counter_V = sec_counter;sei();					//Update volatile version of second_counter
newline();return clock_restore_time;}						//Return "clock_restore_time" to "main loop"



/*****************************************************************************************************************/

long restore_stop_watch(){									//Restores SW time by subtracting the current time from the value stored in "clock_time"
unsigned long time, SW_restore_time;
char x;
time = 8640000 + (sec_counter * 100) + ms_counter - clock_time_long;		// Computes the updated value of SW time
if (time >= 8640000) time -= 8640000;						//Compensate for 24 Hr roll-over
sec_counter = time/100;										//Calculate new value of "sec_counter" and "ms_counter"
ms_counter = time%100 - 2;									//2mS fudge factor required for mseconds
update_7_seg_display(); 									//Run "update_7_seg_display()" to complete the current I2C transaction
x=ms_counter;												//Record "ms_counter"
SW_restore_time = sec_counter;								//saves "sec_counter" in "SW_restore_time"							
Calculate_time();											//Calculate time Hr:Min:sec
digits[1] = ms_counter/10 + '0';							//Calculate mS display MSB
digits[0] = ms_counter%10 + '0';							//Calculate mS display LSB
Update_time_on_screen; ms_on_screen_update;					//Update PC screen					
payload = 8;												//Sets the payload to 8 ahead of next I2C transaction (update full disdplay)
while(ms_counter==x);										//Wait for next interrupt (ms_counter increments from x to x+1)
TWI_flag = 0;												//Clear TWI_flag
Update_time_on_screen; ms_on_screen_update;					//Full screen update
update_7_seg_display();										//Full display update (completes the current I2C transaction)
if(ms_counter == 99)payload=8; else payload=2;				//Enables contiguous 8 digit updates when necessary
cli();sec_counter_V = sec_counter;	sei();					//Update volatile version of the sec_counter
return SW_restore_time;}									//Return "SW_restore_time" to "main loop"



/*****************************************************************************************************************/
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

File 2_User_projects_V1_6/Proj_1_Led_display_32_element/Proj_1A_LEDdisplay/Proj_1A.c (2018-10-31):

/*Proj_1A_LEDdisplay
***************************************************/

/*
THE FIRST PROGRAM:  Learning to drive the led segments.

This uses the display to generate a simple pattern that repeats endlessly.



LEARNING SOMETHING ABOUT THE C PROGRAMMING LANGUAGE (C)

1.	The "main" routine:
When power is applied or immediately after programming, program execution starts with the "main" routine.  
Note the "{}" symbols used to initiate and terminate this routine.

2.	The "for-loop":
Code within the {} brackets is executed 16 times as "m" increments from 1 to 16.  
In C, “m++;” is shorthand notation for add 1 to m.  
When “m” gets to 17 program execution jumps to the statement “SW_reset;”.

3.	Variables:
PORT_1 and “m” are names assigned to variables.  
They can take on numeric values which are the results of logical or arithmetic operations.  
In this case PORT_1 is initialised to 1 and then doubled every time that the "for-loop" repeats  
(the shift symbol “<<” followed by 1 is equivalent to multiply by 2).

4.	Comments:
No text in green needs retyping to get the program working. This is what is called "comment".



DISCOVERING THE ATMEGA HARDWARE (HW)

1.	The Central Processor Unit (CPU):
This is the unit that performs the arithmetic and logical operations (and, or, not etc.) already referred to.

2.	Data memory also know as SRAM:
This is memory space in which variables such as PORT_1 and “m” are stored.    
In this case the variables are defined as integer and 16 binary digits (bits) are reserved for each one.  
16 bit numbers can hold 2^16 values.  
PORT_1 which is unsigned can hold values from 0 to 65535. 
“m” which is signed (by default) can hold numbers between -32,678 and +32677.

3.	Output ports:
Output ports are connected to the display and used to power the segments.  
For each bit of PORT_1 there are corresponding segments in the display.  
For each bit that is set to 1 these segments are illuminated and each each bit that is set to 0 they are not.

4.	I2C bus:
This enables data to be shared between the Atmega devices. 
Here it is used to enable user code running on the Atmega 168 to drive the display which is under 
the control of the Atmega 328.  

5.	A HW timer T0 that pauses program execution for 60ms in this case.



INTRODUCING THE PROJECT FIRM WARE (FW)

1. 	The "setup_HW" macro:
This is a code segment that sets up Atmega 168 HW (hard ware). 
For example it determines which pins are to be configured as outputs and which as inputs.

2.	The I2C subroutine "I2C_Tx_2_integers":
This sends 32 data bits (each 0 or 1) over the I2C bus to the Atmega 328 where the 
mini-OS uses them to control illumination of the 32 vertical led segments.

3.	The "SW_reset" statement:
This causes program execution to repeat from the beginning as it does for a 
Power on Reset (POR) when power is first applied.

4.	The .h file:
This gives details of "setup_HW",  and "SW_reset", and the location of the "I2C subroutine".  
It also tells the compiler about certain WinAVR files that will be required. 



DRIVING THE DEVELOPMENT TOOLS

To create the .hex file click on “tools” and then select “Make All”.
Select “Make Clean” to delete all extra files generated except the .hex

Note: The Makefile has been slightly edited to ensure that the .hex file is not also deleted. */




//THE PROGRAM STARTS HERE


 

#include "Proj_1A_header_file.h"				//Provides details of resources provided by the complier and project_SW
												//including "setup_HW", the I2C subroutine and "SW_reset"


int main (void){								//The "main" routine lies between a pair of {} brackets.

unsigned int PORT_1=1;							//PORT_1 is an address in data memory initially set to 1 (binary 0000000000000001)
												//Note: that PORT_1 holds 16 bits (binary digits) of data 
setup_HW;					

	for(int m = 1; m < 17; m++){				//Code between the {} brackets is repeated 16 times 						
												//as m increments from 1 to 16	(m++ is shorthand for increment m)
		I2C_Tx_2_integers(PORT_1, PORT_1);				

		Timer_T0_10mS_delay_x_m(6);				//This subroutine generates a 10mS delay that is repeated 6 times		
		PORT_1 = PORT_1 << 1;					//The contents of address "PORT_1" are shifted one place left
		}SW_reset;								//every time that the "for-loop" is executed
}

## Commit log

2018-10-26 Update Documentation/PCB 111000 leaflet.pdf
2018-10-29 Update Documentation/System documentation/6_Calibrating the devices.pdf
2018-10-29 Update Documentation/System documentation/9_Display wiring.pdf
2018-10-30 Update 1_Documentation/System documentation/6_Calibrating the devices.pdf
2018-10-30 Update 1_Documentation/4_System documentation/6_Calibrating the devices.pdf
2018-10-30 Update 3_mini-OS/I2C_V12_0_CC/makefile
2018-10-30 Update 3_mini-OS/I2C_V12_0_CC/Resources_CC/I2C_V12_0_CC_osccal_calibration subroutintes.c
2018-10-30 Update 3_mini-OS/I2C_V13_0_CA/makefile
2018-10-30 Update 3_mini-OS/I2C_V13_0_CA/Resources_CA/I2C_V13_0_CA_osccal_calibration subroutintes.c
2018-10-30 Update 5_Clock_calibration/Resources/calibration subroutintes.c
2023-06-23 Create I_O_from switches.h
2023-06-24 Create PCB 111000_CC.cmp
2023-06-24 Create PCB 111000_CC.drd
2023-06-24 Create PCB 111000_CC.dri
2023-06-24 Create PCB 111000_CC.gpi
2023-06-24 Create PCB 111000_CC.plc
2023-06-24 Create PCB 111000_CC.sol
2023-06-24 Create PCB 111000_CC.stc
2023-06-24 Create PCB 111000_CC.sts
2023-06-24 Create PCB 111000_CC_Manufacturing drawings.zip
2023-06-24 Create PCB 111000_CC_parts_list.txt
2023-06-24 Create PCB 111000_CC.sch
    [PCB 111000_CC.sch]
2023-06-24 Create PCB 111000_CC.brd
    [PCB 111000_CC.brd]
2023-06-24 Create PCB 111000_CC.b##
2023-06-24 Create PCB 111000_CA_parts_list.txt
2023-06-24 Create PCB 111000_CA_Manufacturing drawings.zip
2023-06-24 Create PCB 111000_CA.sts
2023-06-24 Create PCB 111000_CA.stc
2023-06-24 Create PCB 111000_CA.sol
2023-06-24 Create PCB 111000_CA.plc
2023-06-24 Create PCB 111000_CA.gpi
2023-06-24 Create PCB 111000_CA.dri
2023-06-24 Create PCB 111000_CA.drd
2023-06-24 Create PCB 111000_CA.cmp
2023-06-24 Create PCB 111000_CA.brd
    [PCB 111000_CA.brd]
2023-06-24 Create PCB 111000_CA.sch
    [PCB 111000_CA.sch]
2023-06-24 Create .~lock.PCB111000_investigation.odt#
2023-06-24 Update .~lock.PCB111000_investigation.odt#
2023-06-26 Create I2C_V20_0_CA_part_1
2023-06-26 Create I2C_V20_0_CA_part_2
2023-06-26 Create I2C_V20_0_CC_part_1
2023-06-26 Create I2C_V20_0_CC_part_2
2023-06-26 Create I2C_V20_0_osccal_ subroutintes_basic.c
